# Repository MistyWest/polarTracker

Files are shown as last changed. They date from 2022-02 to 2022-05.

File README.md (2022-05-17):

# WWF ARGOS Tracker

This is the open-source repo for Polar Bear Tracker designed by MistyWest and IDEO for the World Wildlife Fund and US Fish & Wildlife Services. 
For more information see the [blog post](https://www.mistywest.com/posts/project/wwf-polar-bear-tracker/) from MistyWest on the project.

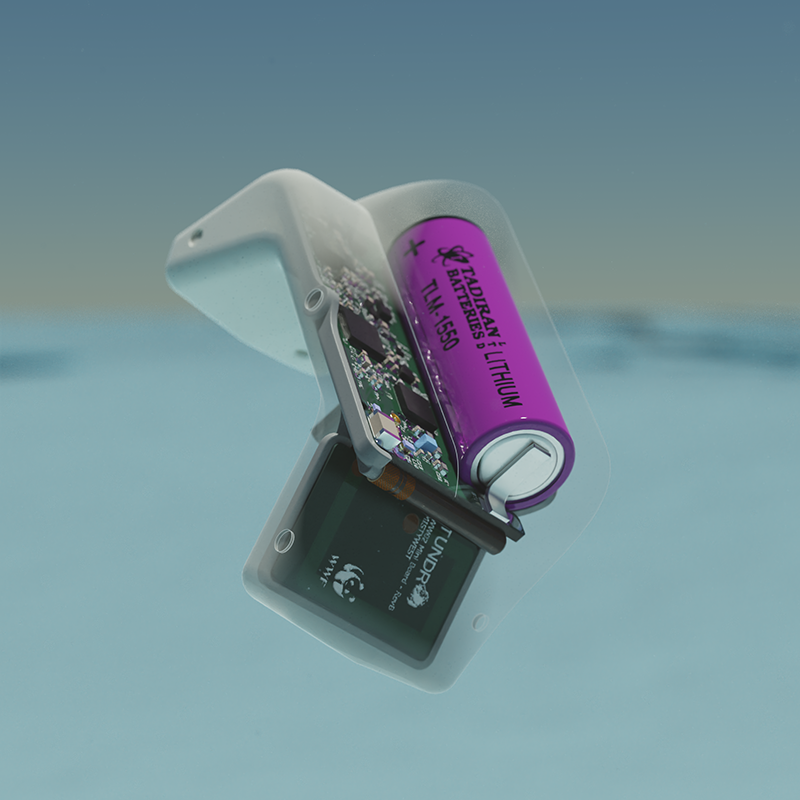
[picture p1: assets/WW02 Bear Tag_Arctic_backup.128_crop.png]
Polar tracker

FWS |  MW | WWF
:-------------------------:|:-------------------------:|:-------------------------:
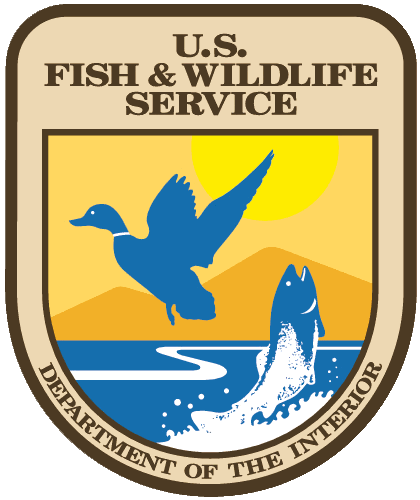
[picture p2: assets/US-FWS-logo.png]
FWS
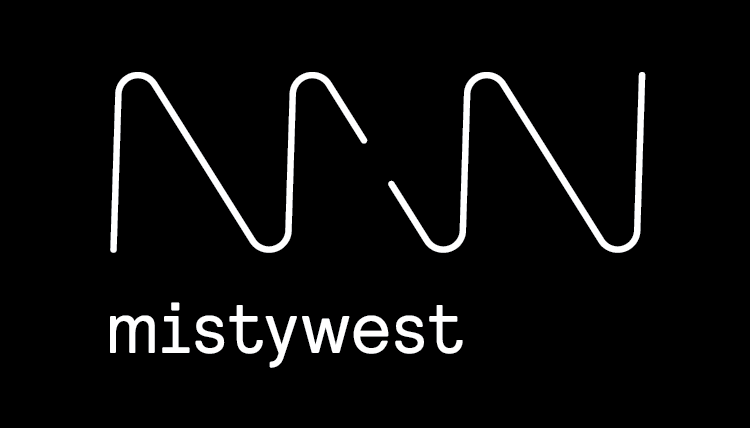
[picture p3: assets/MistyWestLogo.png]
MistyWest
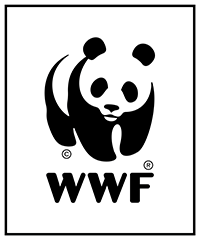
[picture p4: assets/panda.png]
WWF
  |   | 

# Usage Guide

## Quick Start
### EE
- [Design Files](Electrical/Design%20Files)
- [PCB Output Files](Electrical/PCB%20Output%20Files)
### ME
- [Mold Files](Mechanical/Mold%20v3)
### FW
- [Bootloader](Firmware/wwf_bootloader)
- [Firmware](Firmware/ww02Firmware)
    > 1. Initially the board need to be flash using a J-link \
      2.  Any addtionally changes can be be done with the NRF Connect app
      >

## main.c

This is the starting/jump off point for the code. All major threads are started/initialized here.  
You can control the sequence of thread start-up or enable/disable threads via 
```
project_settings.h
```

## Logging/CLI
These are actually two different components.  
CLI is a command line interface which allows for manual
control.  This can be used for debugging and/or user interface.  You can send Text to the terminal
through API called seen in:
```
mw_cli_thread.h
```

Logging is primary for debugging code during development. A wrapper is created around the Nordic SDK
Logging module.  it must be enabled in the SDK config file, where you can also specify either a UART 
or RTT (J-Link) physical interface. This should be a different interface than CLI
```
sdk_config.h

#define NRF_LOG_ENABLED 1

#define NRF_LOG_BACKEND_UART_ENABLED (0:1)

#define NRF_LOG_BACKEND_RTT_ENABLED (0:1)
```

## ADC
The ADC thread uses the Nordic SAADC peripheral driver and is provided as an example of ADC usage.
SAADC must be enabled in the SDK Config file
```
sdk_config.h

#define NRFX_SAADC_ENABLED 1
```

## Current Status:
- Device only works when compiled under DEBUG mode in the Makefile.  Core issue is related to the interface between the nRF52 and ARTIC chip.

## Documentation

Doxygen is used to build the source code documentation. Go to the [downloads page](http://www.doxygen.nl/download.html), scroll down to **Sources and Binaries** and select the latest archive for Linux, Windows, or Mac.

Or if on Linux, just do:

```
sudo apt install doxygen
```

To build the documentation:

```
cd _docs/
doxygen
```

Then use your browser to open `_docs/html/index.html`.

## Contributors
MistyWest
- Kevin Lockwood
- Daniel Law
- Fred Huang
- Victor Hu
- John Turner
- Sean Edmond
- Justin Lam
- Nathan Van Rumpt
- Ryan Wilson
- Michelle St. Martin
- Elisabeth Kruger
- Kayvon Shakeri
- Peter Bronk
- Remy Pieron
- Phil Tsao

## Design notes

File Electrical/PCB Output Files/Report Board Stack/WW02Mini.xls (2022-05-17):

Board Stack Report
Stack Up |  |  | Layer Stack
Layer | Board Layer Stack | Flex | Name | Material | Thickness | Constant
1 |  |  | Top Paste
2 |  |  | Top Overlay
3 |  |  | Top Solder | Solder Resist | 0.60mil | 3.5
4 |  |  | Top Layer | Copper | 1.40mil
5 |  |  | Dielectric 1 | FR-4 | 10.00mil | 4.2
6 |  |  | Signal Layer 1 | Copper | 0.70mil
7 |  |  | Dielectric 3 | PP-006 | 3.30mil | 4.1
8 |  |  | Dielectric 6 | Core-009 | 10.00mil | 4.5
9 |  |  | Dielectric 7 | PP-006 | 2.90mil | 4.1
10 |  |  | Signal Layer 2 | Copper | 0.70mil
11 |  |  | Dielectric 4 |  | 2.00mil | 4.2
12 |  |  | Signal Layer 3 | Copper | 0.70mil
13 |  |  | Dielectric 9 | PP-006 | 3.40mil | 4.1
14 |  |  | Dielectric 8 | Core-009 | 10.00mil | 4.5
15 |  |  | Dielectric 5 | PP-006 | 3.30mil | 4.1
16 |  |  | Signal Layer 4 | Copper | 0.70mil
17 |  |  | Dielectric 2 |  | 10.00mil | 4.2
18 |  |  | Bottom Layer | Copper | 1.40mil
19 |  |  | Bottom Solder | Solder Resist | 0.60mil | 3.5
20 |  |  | Bottom Overlay
21 |  |  | Bottom Paste
 | Height : 61.70mil | Height : 29.70mil

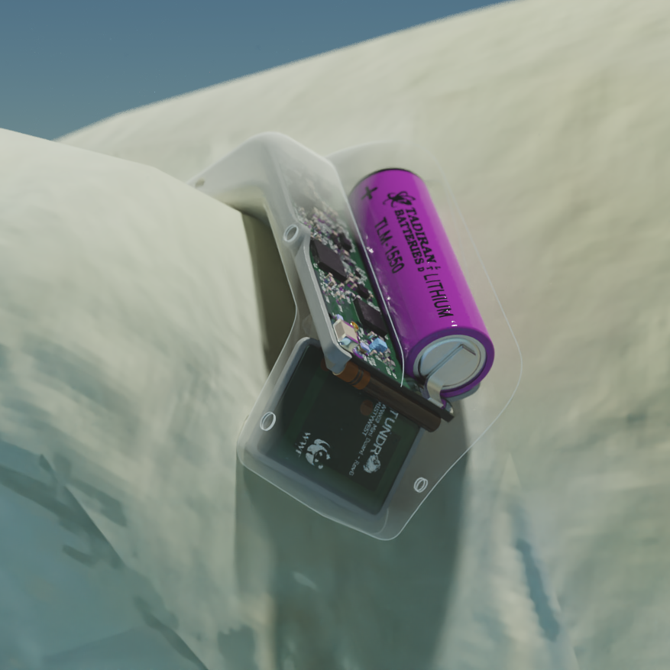
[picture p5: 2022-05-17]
Mechanical/Photos/WW02_Render01.png

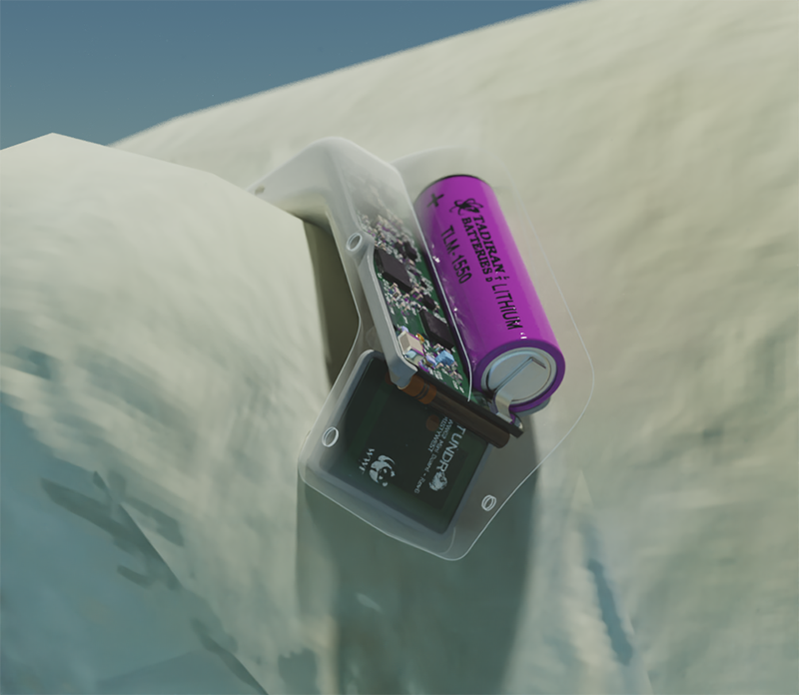
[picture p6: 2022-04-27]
Mechanical/Photos/WW02 Bear Tag_Arctic_backup3.126.png

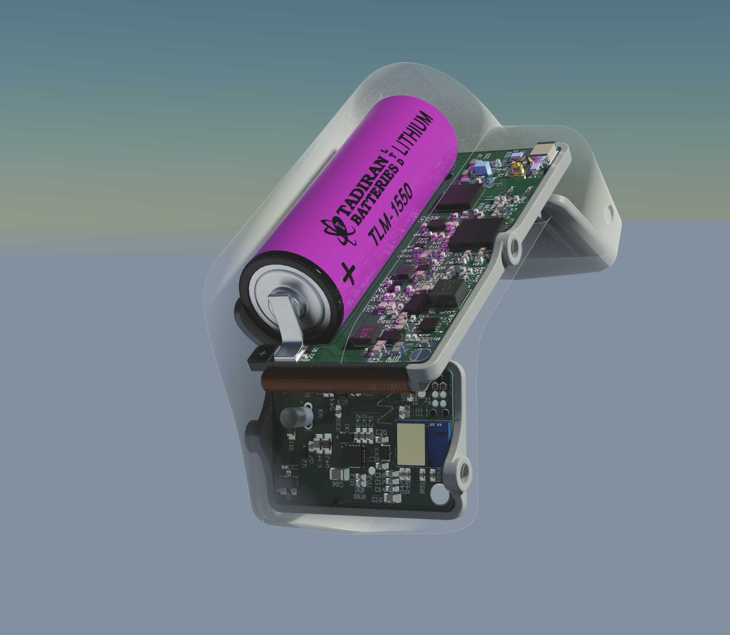
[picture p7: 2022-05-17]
Mechanical/Photos/WW02 Bear Tag_Arctic_backup.135.png

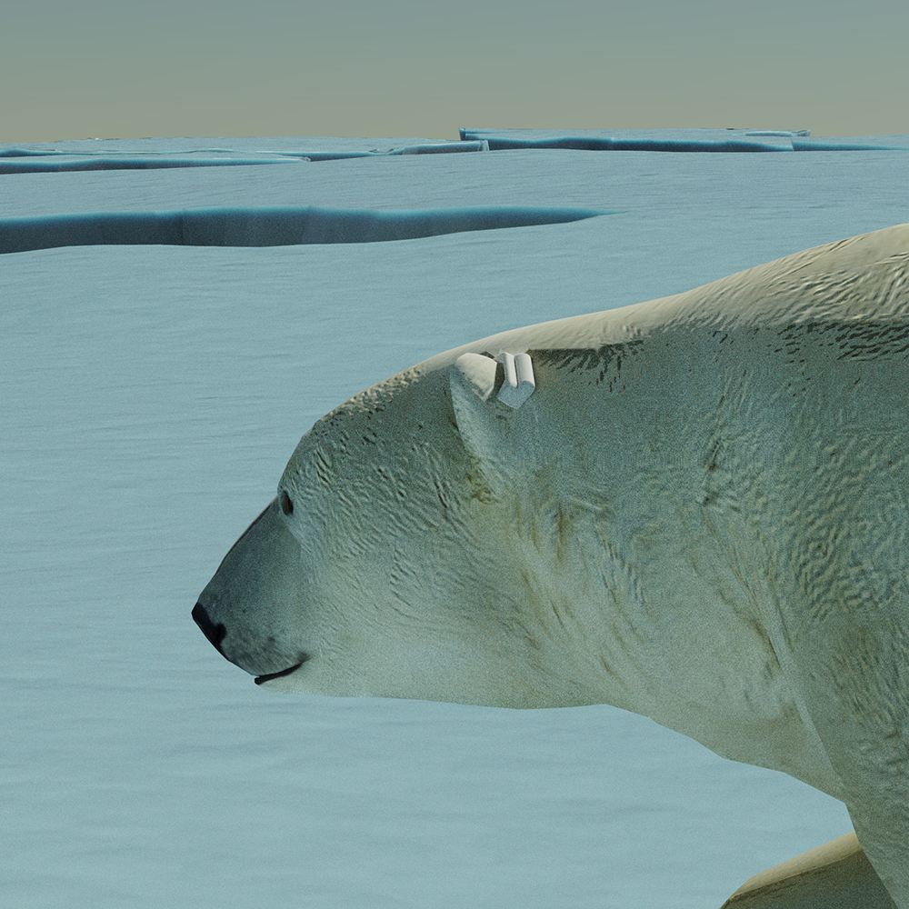
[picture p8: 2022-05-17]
Mechanical/Photos/WW02_Render02.png

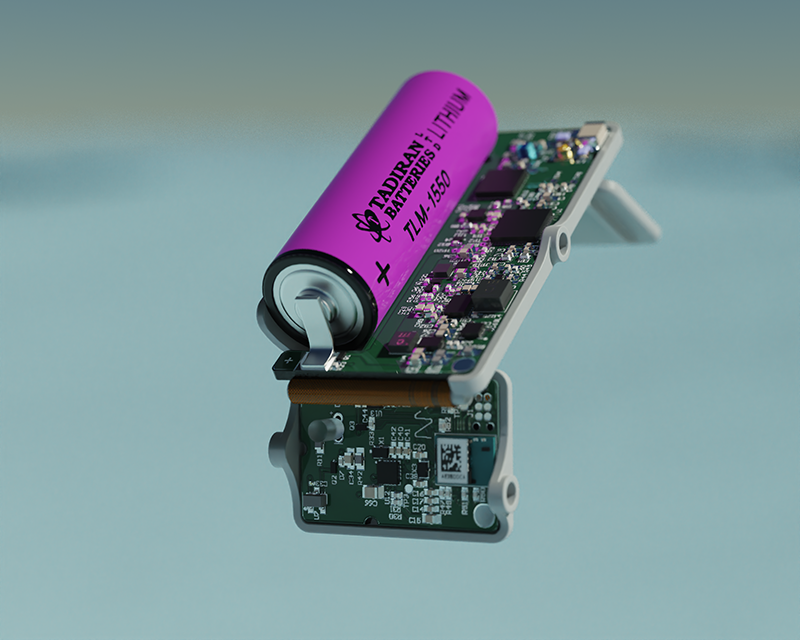
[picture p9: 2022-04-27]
Mechanical/Photos/WW02 Bear Tag_Arctic_backup.137.png

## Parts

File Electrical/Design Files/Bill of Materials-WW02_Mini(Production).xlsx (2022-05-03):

Designator | Quantity | Comment | Description | Manufacturer | Manufacturer Part Number
BT1 | 1 | TLP-96311/A/ST |  | Tadiran | TLP-96311/A/ST
C1 | 1 | 22µF | CAP CER 22UF 6.3V X5R 0603 ±10% | Samsung Electro-Mechanics America, Inc. | CL10A226KQ8NRNE
C2, C14, C18, C40, C43, C46, C47 | 7 | 1µF | CAP CER 1UF 6.3V X7R 0402 ±10% | Samsung Electro-Mechanics America, Inc. | CL05B105KQ5NQNC
C3, C4, C6, C8, C10, C12, C15, C16, C19, C28, C41, C44, C61 | 13 | 100nF | CAP CER 0.1UF 10V X7R 0402 ±5% | Samsung Electro-Mechanics America, Inc. | CL05B104JP5NNNC
C5, C7, C9, C11, C13, C62 | 6 | 22pF | CAP CER 22PF 50V C0G/NP0 0402 ±5% | Samsung Electro-Mechanics America, Inc. | CL05C220JB5NNNC
C17, C25, C26, C27, C30, C31, C32 | 7 | 22µF 6.3V X5R | CAP CER 22UF 6.3V X5R 0603 ±10% | Samsung Electro-Mechanics America, Inc. | CL10A226KQ8NRNE
C20, C38 | 2 | 20pF | CAP CER 20PF 50V C0G/NP0 0402 ±5% | Samsung Electro-Mechanics America, Inc. | CL05C200JB5NNNC
C21 | 1 | 1.8pF | CAP CER 1.8PF 50V C0G/NP0 0402 ±0.25pF | Samsung Electro-Mechanics America, Inc. | CL05C1R8CB5NNNC
C22, C23, C35, C60 | 4 | 10pF | CAP CER 10PF 50V C0G/NP0 0402 ±0.25pF, CAP CER 10PF 50V C0G/NP0 0402 ±0.5pF | Samsung Electro-Mechanics America, Inc. | CL05C100CB5NNNC, CL05C100DB5NNNC
C24, C29, C34 | 3 | 2.2uF | CAP CER 2.2uF 6.3V X7R 0603 ±10% | Samsung Electro-Mechanics America, Inc. | CL10B225KQ8NNNC
C33 | 1 | 15nF | CAP CER 15nF 6.3V X5R 0201 ±10% | Samsung Electro-Mechanics America, Inc. | CL03A153KQ3NNNC
C36, C37 | 2 | 10µF 6.3V X5R | CAP CER 10UF 6.3V X5R 0603 ±10% | Samsung Electro-Mechanics America, Inc. | CL10A106KQ8NNNC
C39, C49 | 2 | 100pF | CAP CER 100PF 50V C0G/NP0 0402 ±5% AEC-Q200 | Samsung Electro-Mechanics America, Inc. | CL05C101JB51PNC
C42, C90 | 2 | 47pF | CAP CER 47PF 50V C0G/NP0 0402 ±5%, CAP CER 47PF 50V C0G/NP0 0402 ±5% AEC-Q200 | Samsung Electro-Mechanics America, Inc. | CL05C470JB5NNNC, CL05C470JB51PNC
C45, C48 | 2 | 220nF | CAP CER 0.22UF 10V X7R 0402 ±10% | Samsung Electro-Mechanics America, Inc. | CL05B224KP5NNNC
C50 | 1 | 5.5-30pF 125V Trimmer | CAP TRIMMER 5.5-30PF 125V SMD | Knowles Voltronics | JR300
C51 | 1 | 33pF | CAP CER 33PF 50V C0G/NP0 0402 ±5% | Samsung Electro-Mechanics America, Inc. | CL05C330JB5NNNC
C63, C64, C89 | 3 | 10nF | CAP CER 10000PF 10V X7R 0402 ±10% | Samsung Electro-Mechanics America, Inc. | CL05B103KP5NNNC
C65 | 1 | 1.0uF | CAP CER 1.0uF 6.3V X7R 0603 ±10% | Samsung Electro-Mechanics America, Inc. | CL10B105KQ8NNN
C66 | 1 | 47µF | CAP CER 47UF 6.3V X5R 0805 ±20% | Samsung Electro-Mechanics America, Inc. | CL21A476MQCLRNC
C67, C68 | 2 | 470nF | CAP CER 470nF 6.3V X5R 0201 ±10% | Samsung Electro-Mechanics America, Inc. | CL03A474KQ3NNNC
C91 | 1 | 680pF | CAP CER 680PF 50V C0G/NP0 0402 ±5% | Samsung Electro-Mechanics America, Inc. | CL05C681JB5NNNC
C92 | 1 | 6.8pF | CAP CER 6.8PF 50V C0G/NP0 0402 ±0.25pF | Samsung Electro-Mechanics America, Inc. | CL05C6R8CB5NNNC
D5 | 1 | WP710A10LSECK/J3 | Red 625nm LED Indication - Discrete 1.8V Radial | Kingbright | WP710A10LSECK/J3
D7 | 1 | CDBQR0130L | Diode Schottky 30V 100mA Surface Mount 0402/SOD-923F | Comchip Technology | CDBQR0130L
FB1, FB2, FB4, FB7, FB8, FB9, FB10 | 7 | BLM15AG221SN1D | Chip Ferrite Bead for General Use, 220 Ohm, 450 mA, -55 to 125 degC, 1 x 0.5 x 0.55 mm SMD, Tape and Reel | Murata | BLM15AG221SN1D
J2, J3 | 2 | CONNECTOR COAX-M 2GND | CONN RECPT ULTRA-MINI COAX SMD | HIROSE | U.FL-R-SMT(10)
L3 | 1 | 2.2uH 1.4A | XFL3012-222ME_ | CoilCraft | XFL3012-222ME_
L4 | 1 | 2.2u | XAL4020-222ME | CoilCraft | XAL4020-222ME
L5 | 1 | 2.2uH | XPL2010-222ML | CoilCraft | XPL2010-222ML
L8 | 1 | 15nH | FIXED IND 15NH 1.5A 120 MOHM | MuRata | LQW2BAN15NG00L
L9 | 1 | 6.8nH | 0603HP-6N8X_E_ | Coilcraft | 0603HP-6N8X_E_
Q1, Q3, Q4, Q5 | 4 | CSD23285F5T | P-Channel 12V 5.4A (Ta) 500mW (Ta) Surface Mount 3-PICOSTAR | Texas Instruments | CSD23285F5T
Q2, Q6 | 2 | CSD17585F5T | N-Channel 30V 5.9A (Ta) 500mW (Ta) Surface Mount 3-PICOSTAR | Texas Instruments | CSD17585F5T
R1, R8, R47, R48, R49, R50, R51, R52, R53 | 9 | 0 | RES SMD 0.0OHM JUMPER 1/16W 0402 | Yageo | RC0402JR-070RL
R2, R3 | 2 | 100k | RES SMD 100K OHM 1% 1/10W 0402 | Panasonic Electronic Components | ERJ-2RKF1003X
R5 | 1 | 5.6 | RES SMD 5.6 OHM 1% 1/4W 0603 | Panasonic | ERJ-3BQF5R6V
R6, R7 | 2 | 910 | PANASONIC ERJPA3F9100V RESISTOR, ERJP, 910 OHM, 0603, 0.25W, 1% | Panasonic | ERJ-PA3F9100V
R9 | 1 | 33k | RES SMD 33K OHM 1% 1/10W 0402 | Panasonic Electronic Components | ERJ-2RKF3302X
R11 | 1 | 750R | 750R 0.1W ±5% | Yageo | RC0603JR-07750RL
R15, R20 | 2 | 1M | RES SMD 1M OHM 1% 1/16W 0402 | Yageo | RC0402FR-071ML
R16 | 1 | 402k | RES SMD 402K OHM 1% 1/10W 0402 | Panasonic Electronic Components | ERJ-2RKF4023X
R17, R18 | 2 | 0R | 0R 0.1W | Yageo | RC0603JR-070RL
R19 | 1 | ERT-J0ER104HM | NTC Thermistor 100k 0402 (1005 Metric) | Panasonic Electronic Components | ERT-J0ER104HM
R21, R23, R32, R33, R56 | 5 | 3.6M | RES SMD 3.6M OHM 1% 1/16W 0402 | Yageo | RC0402FR-073M6L
R22 | 1 | 1.74M | RES SMD 1.74M OHM 1% 1/16W 0402 | Yageo | RC0402FR-071M74L
R24 | 1 | 1.3M | RES SMD 1.3M OHM 1% 1/16W 0402 | Yageo | RC0402FR-071M3L
R25 | 1 | 32.4k | RES SMD 32.4K OHM 1% 1/10W 0402 | Panasonic Electronic Components | ERJ-2RKF3242X
R26 | 1 | 20k | RES SMD 20K OHM 1% 1/10W 0402 | Panasonic Electronic Components | ERJ-2RKF2002X
R30, R31, R36, R37 | 4 | 4.7k | RES SMD 4.7K OHM 1% 1/10W 0402 | Panasonic Electronic Components | ERJ-2RKF4701X
R42, R59, R60 | 3 | 4.7M | RES SMD 4.7M ±1% 0.1W, 1/10W 0603 | Yageo | RC0603FR-074M7L
R43, R44, R45 | 3 | 3.3M | RES SMD 3.3M OHM 1% 1/16W 0402 | Yageo | RC0402FR-073M3L
R46 | 1 | 5.1M | RES SMD 5.1M OHM 1% 1/16W 0402 | Yageo | RC0402FR-075M1L
R54, R58 | 2 | 1M | RES SMD 1M OHM 1% 1/10W 0402 | Panasonic Electronic Components | ERJ-2RKF1004X
R66 | 1 | 27.4k | RES SMD 27.4KOHM 0.1% 1/16W 0402 ±10ppm/°C | TE Connectivity Passive Product | RN73C1E27K4BTD
U1 | 1 | ARTIC | Ansem ARTIC | Ansem | ARTIC
U2 | 1 | BMD-350-A-R | MOD BLE 4.2 NORDIC NRF52832 SOC | Rigado, Inc. | BMD-350-A-R
U3 | 1 | RFFM6404 | Transmit/Receive Module, 2.5V to 4.5V, ISM Band, 27.5dBm, 430MHz to 450MHz | Qorvo | RFFM6404TR13
U4 | 1 | LTC3539EDCB#TRPBF | 2 A, 1 MHz / 2 MHz Synchronous Step-Up DC/DC Converter, 8-pin SON (DCB-8), -40 to 85 degC, Pb-Free, Tape and Reel | Linear Technology | LTC3539EDCB#TRPBF
U5 | 1 | LTC3533EDE#TRPBF | 2 A Wide Input Voltage Synchronous Buck-Boost DC/DC Converter, 14-pin SON (DE-14), -40 to 85 degC, Pb-Free, Tape and Reel | Linear Technology | LTC3533EDE#TRPBF
U6 | 1 | TLV3691IDPFR | Comparator General Purpose Push-Pull 6-X2SON (1x1) | Texas Instruments | TLV3691IDPFR
U7 | 1 | AH182-WG-7 | Low Power Hall Effect Switch, 2.5 to 5.5 V, -40 to 85 degC, 3-Pin SC59, RoHS, Tape and Reel | Diodes Incorporated | AH182-WG-7
U8 | 1 | ADP5301ACBZ-1-R7CT-ND | Buck Switching Regulator IC Positive Programmable 0.8V 1 Output 50mA, 500mA 9-WFBGA, WLCSP | ADP5301ACBZ-1-R7 | ADP5301ACBZ-1-R7
U11 | 1 | LPS33HWTR | Pressure Sensor 3.77 PSI ~ 18.27 PSI (26 kPa ~ 126 kPa) Absolute 24 b LGA | STMicroelectronics | LPS33HWTR
U12 | 1 | AM0805AQ | Real Time Clock (RTC) IC 16-VFQFN Exposed Pad | Ambiq Micro, Inc. | AM0805AQ
U13 | 1 | ISM303DACTR | Accelerometer and Magnetometer Sensor I²C, SPI Output | STMicroelectronics | ISM303DACTR
U15 | 1 | LP5900SD-2.7/NOPB | Ultra Low Noise, 150mA Linear Regulator for RF/Analog Circuits Requires No Bypass Capacitor, 6-pin LLP, Pb-Free | Texas Instruments | LP5900SD-2.7/NOPB
X1 | 1 | ABS06-32.768KHZ-1-T | 32.768kHz ±10ppm Crystal 12.5pF 90 kOhms 2-SMD, No Lead | Abracon LLC | ABS06-32.768KHZ-1-T
X2 | 1 | KT2520K26000AAW18TAS | 26MHz TCXO Clipped Sine Wave Oscillator 1.8V 6-SMD, No Lead | Kyocera International Inc. Electronic Components | KT2520K26000AAW18TAS
X3 | 1 | ECS-.327-12.5-12R-C-TR | 32.768kHz ±10ppm Crystal 12.5pF 70 kOhms 2-SMD, No Lead | ECS Inc. | ECS-.327-12.5-12R-C-TR

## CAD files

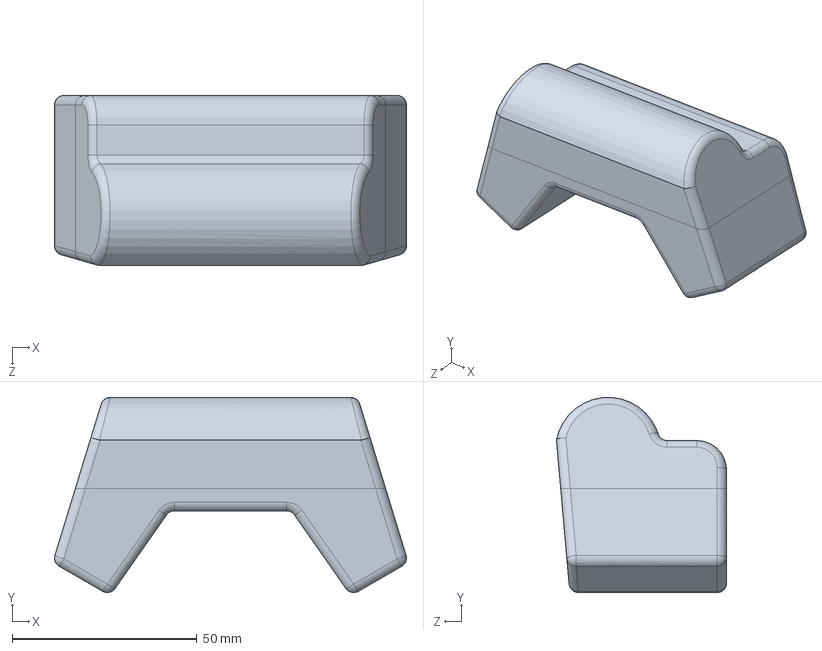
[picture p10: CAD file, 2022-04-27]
Mechanical/3D Printed Mold v3/FULL_3D_printed_enclosure.SLDPRT
95.2 x 52.8 x 46.0 mm

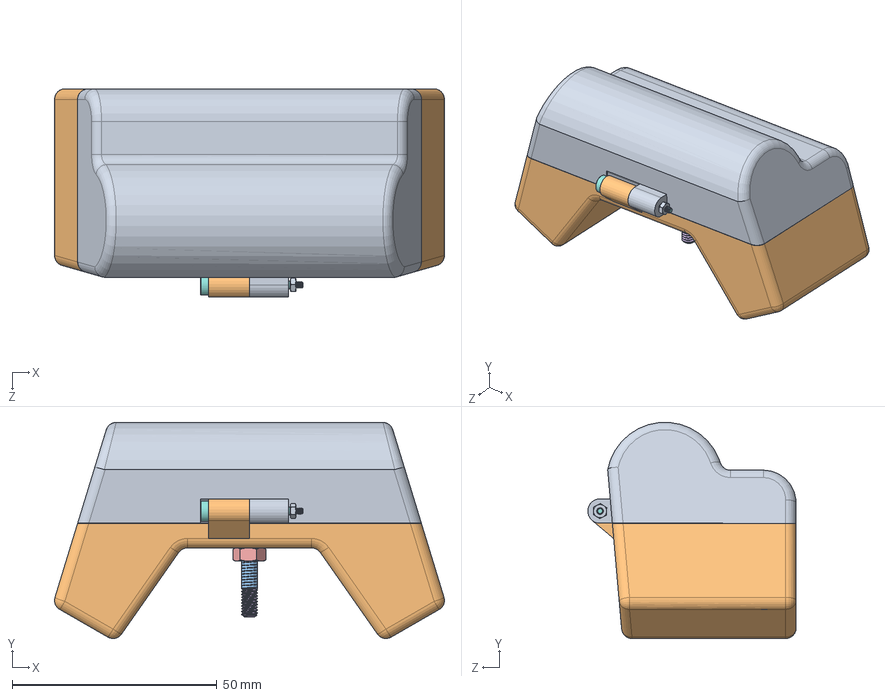
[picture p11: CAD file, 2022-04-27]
Mechanical/3D Printed Mold v3/ASSEM_3D_printed_enclosure.SLDASM
95.2 x 52.8 x 50.8 mm
(B)ear Tag_7_30_2020
ww02_Board_Render
90592A090_Steel Hex Nut
90358A009_Ultra-Low-Profile Socket Head Screw
BOTTOM_3D_printed_enclosure
TOP_3D_printed_enclosure
small_magnet x 8
92981A950_Alloy Steel Shoulder Screws
90591A109_Zinc-Plated Steel Hex Nut

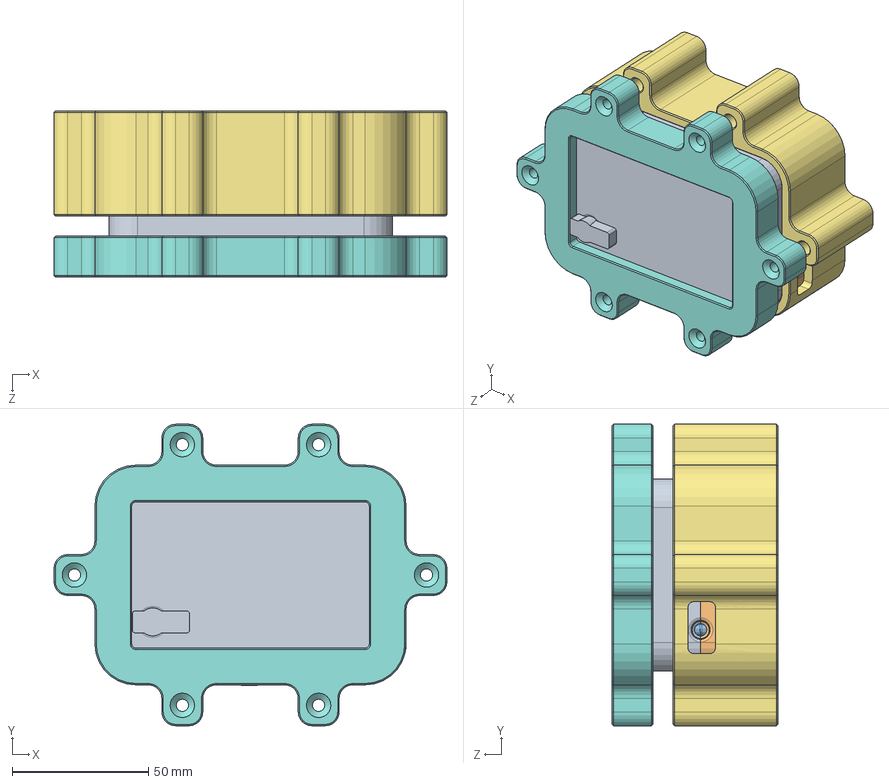
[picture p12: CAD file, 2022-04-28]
Mechanical/Mold v3/ASSEM Potted Case Mold.SLDASM
144.1 x 110.6 x 60.9 mm
Mold v3 Female
(B)ear Tag_7_30_2020
ww02_Board_Render
screw
90592A090_STEEL HEX NUT
Mold v3 Male
Mold Clamp 2
Mold Clamp 1
Plug RevB
wire plug

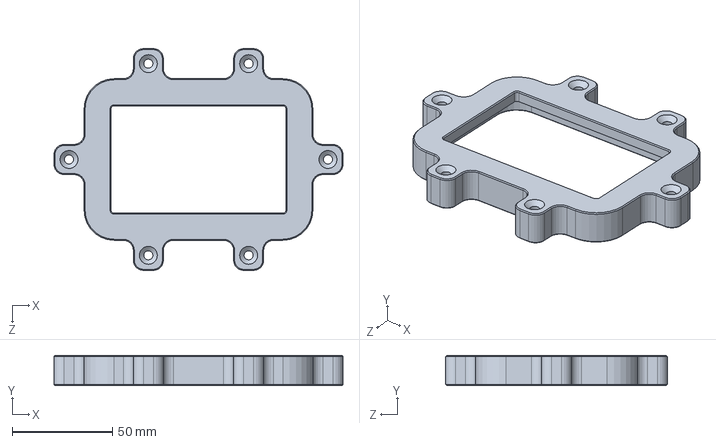
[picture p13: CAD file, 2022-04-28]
Mechanical/Mold v3/Mold Clamp 1.SLDPRT
144.1 x 15.0 x 110.6 mm

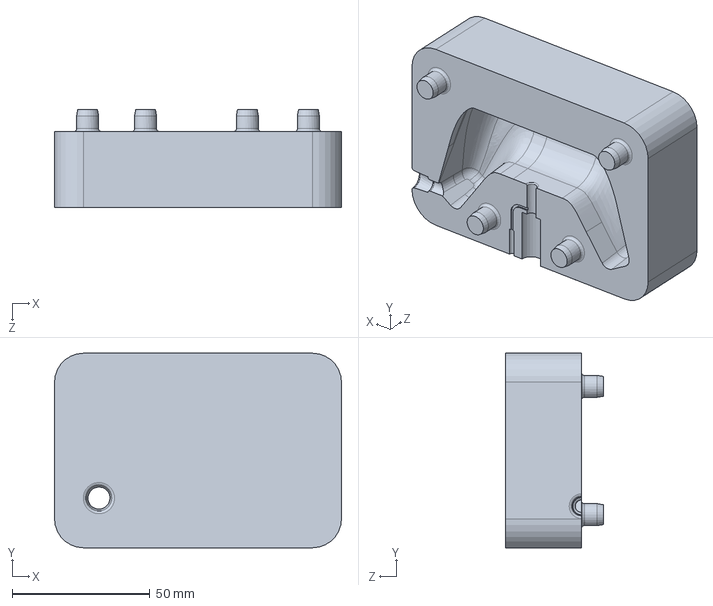
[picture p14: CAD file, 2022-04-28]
Mechanical/Mold v3/Mold v3 Male.SLDPRT
104.0 x 70.5 x 35.6 mm

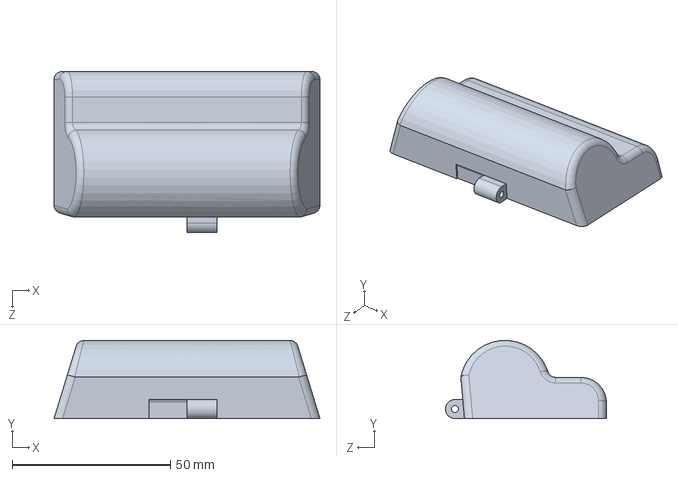
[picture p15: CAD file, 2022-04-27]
Mechanical/3D Printed Mold v3/TOP_3D_printed_enclosure.SLDPRT
83.9 x 24.6 x 50.8 mm

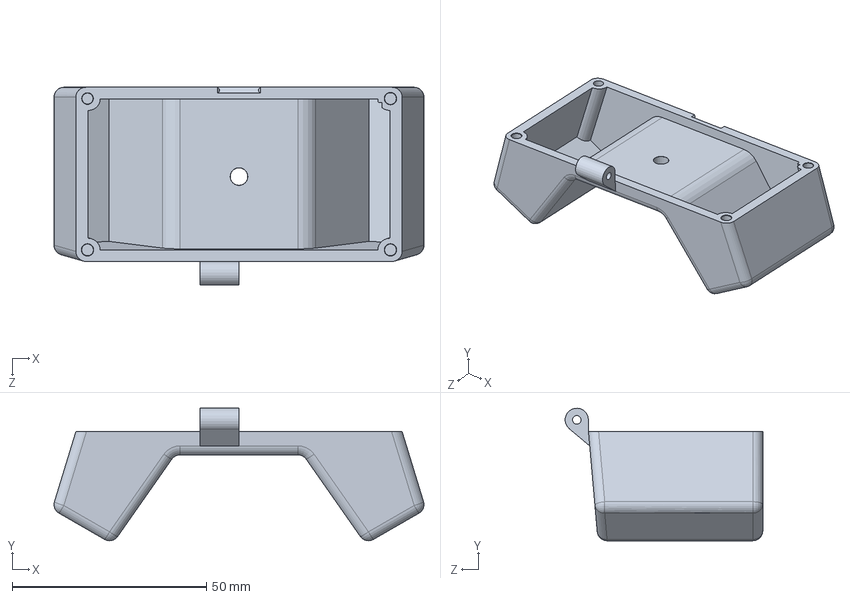
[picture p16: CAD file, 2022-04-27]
Mechanical/3D Printed Mold v3/BOTTOM_3D_printed_enclosure.SLDPRT
95.2 x 34.1 x 50.8 mm

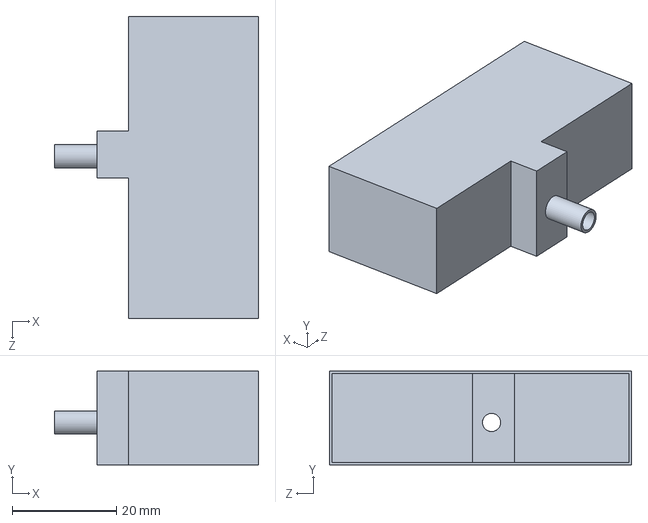
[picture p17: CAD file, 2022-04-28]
Mechanical/Mold v3/urethane reservoir.SLDPRT
39.2 x 18.0 x 58.0 mm

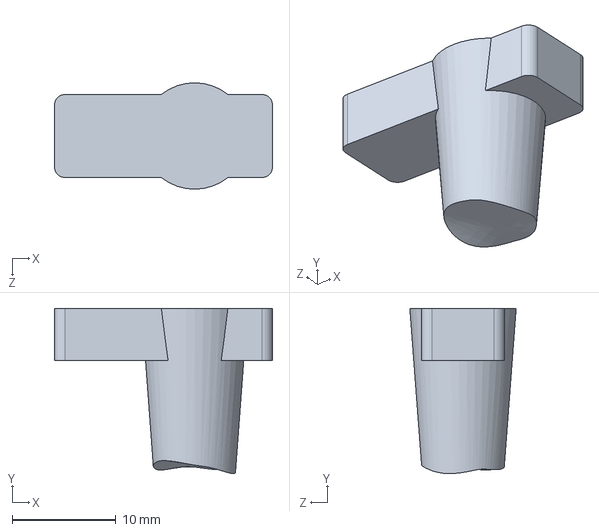
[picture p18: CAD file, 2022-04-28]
Mechanical/Mold v3/Plug RevB.SLDPRT
21.0 x 15.9 x 10.2 mm

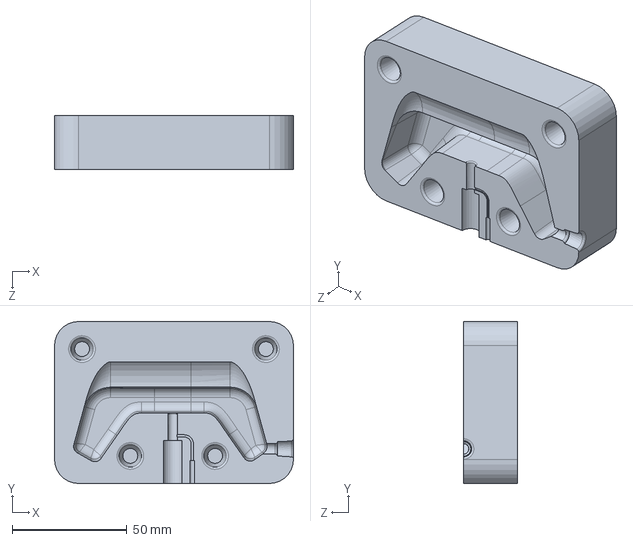
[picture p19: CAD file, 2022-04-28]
Mechanical/Mold v3/Mold v3 Female.sldprt
104.0 x 70.5 x 23.4 mm

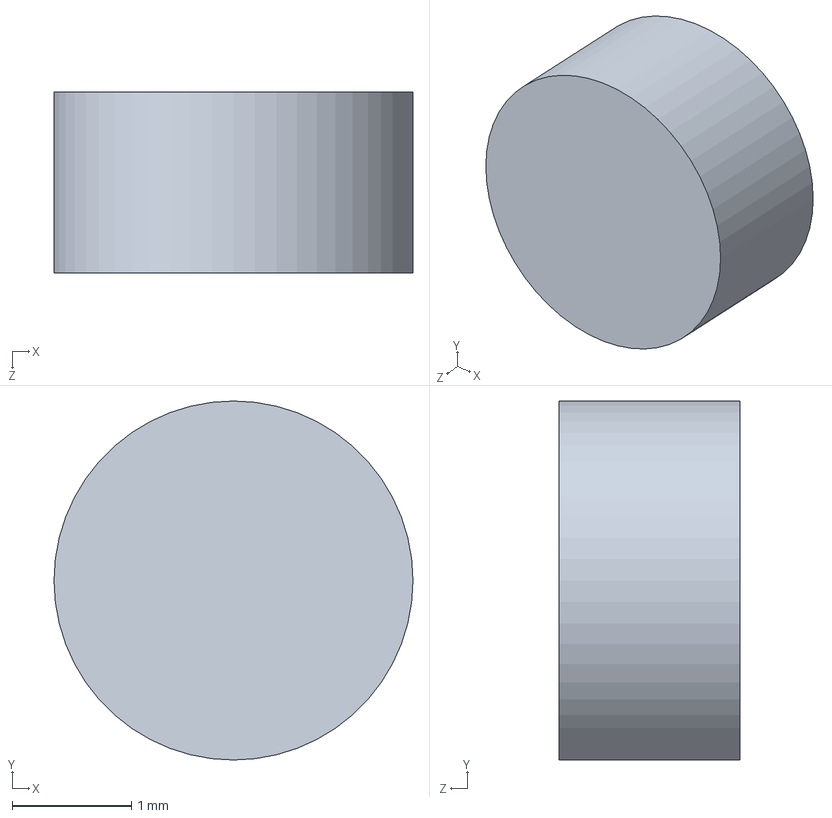
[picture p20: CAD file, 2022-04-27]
Mechanical/3D Printed Mold v3/Hardware/small_magnet.SLDPRT
3.01 x 3.01 x 1.52 mm

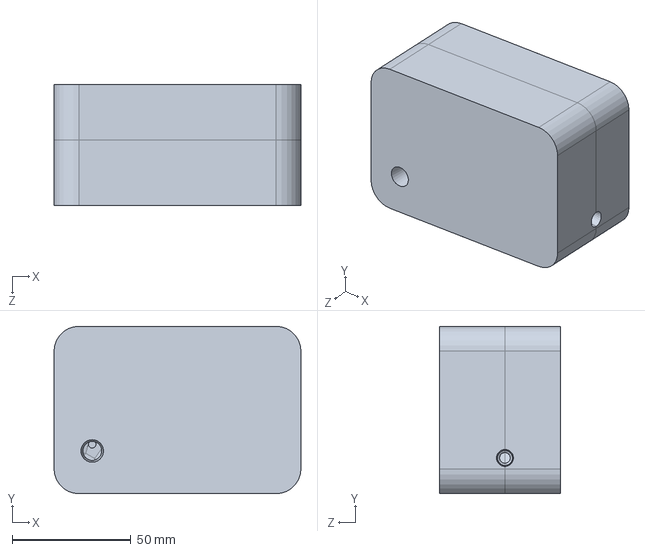
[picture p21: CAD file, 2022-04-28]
Mechanical/Mold v3/Mold v3.sldprt
104.0 x 70.5 x 50.9 mm

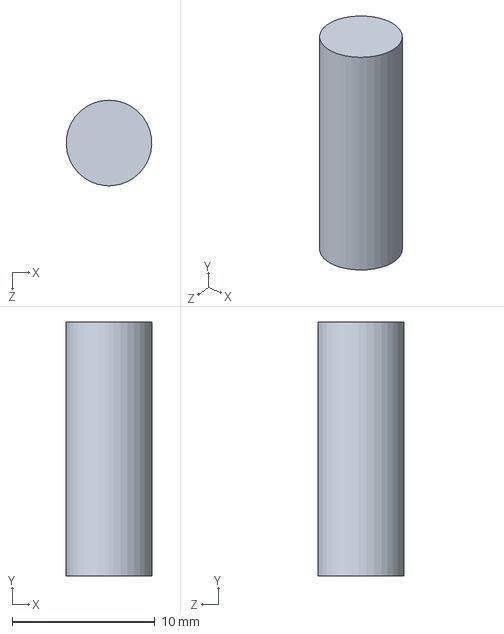
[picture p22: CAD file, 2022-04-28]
Mechanical/Mold v3/wire plug.SLDPRT
5.99 x 17.8 x 6.00 mm

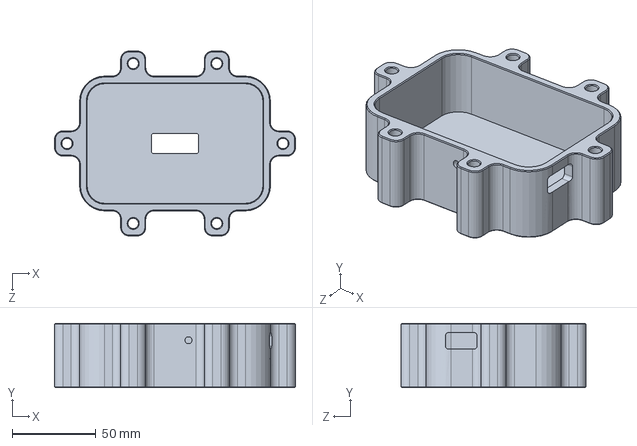
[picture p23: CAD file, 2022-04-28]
Mechanical/Mold v3/Mold Clamp 2.SLDPRT
144.1 x 38.5 x 110.6 mm

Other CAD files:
Mechanical/3D Printed Mold v3/Hardware/90591A109_Zinc-Plated Steel Hex Nut.SLDPRT
Mechanical/Mold v3/Hardware/90592A090_STEEL HEX NUT.SLDPRT
Mechanical/3D Printed Mold v3/Hardware/90358A009_Ultra-Low-Profile Socket Head Screw.SLDPRT
Mechanical/3D Printed Mold v3/Hardware/M4x0.7mmx20mm Ulow_prof.SLDPRT
Mechanical/3D Printed Mold v3/Hardware/90592A090_Steel Hex Nut.SLDPRT
Mechanical/3D Printed Mold v3/Hardware/91829A780_Slotted 18-8 Stainless Steel Precision Shoulder Screw.SLDPRT
Mechanical/3D Printed Mold v3/Hardware/92981A950_Alloy Steel Shoulder Screws.SLDPRT
Mechanical/Mold v3/screw.SLDPRT

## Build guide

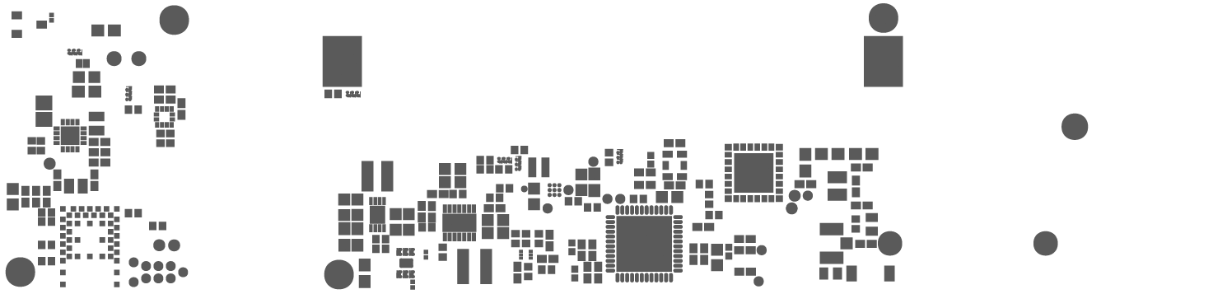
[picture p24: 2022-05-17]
Electrical/PCB Output Files/Gerber/PNG export/Photoshop png export/WW02_0003s_0001_Solder-Pads-copy-3.png

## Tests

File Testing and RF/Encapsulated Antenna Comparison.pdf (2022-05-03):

Valhalla Systems Inc. | April 9, 2021
WWF, Encapsulated Antenna Performance

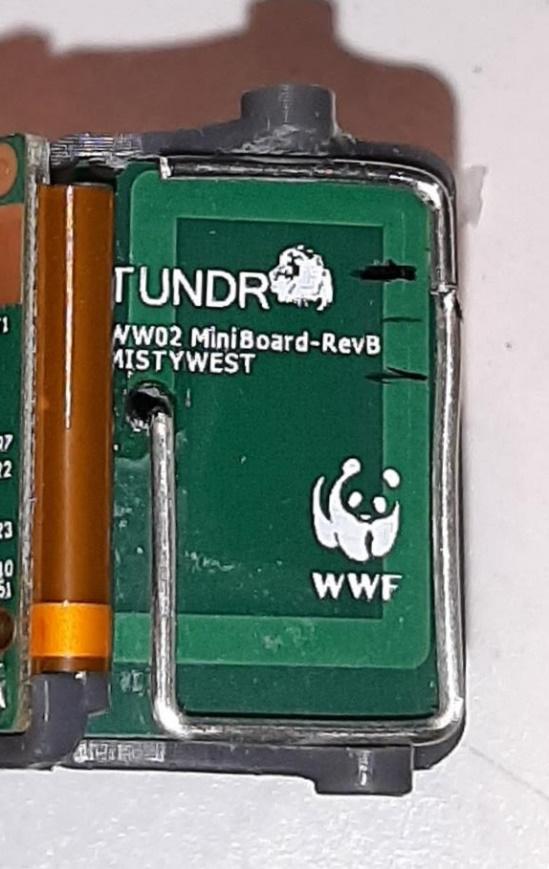
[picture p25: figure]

- Proprietary and Confidential -
Encapsulated Antenna Comparison.docx | ©Valhalla Systems Inc. 2021 | page 1 of 6

The unit encapsulated by Misty West was modifed to extend the length of the resonator into the potting material. A representative sample of the extension is shown below. The resonators on future units should be replaced and trimmed to duplicate the length.

The extension is in the shape of an L, the outside dimensions are 5mm on the short side and 15mm on the long side. This shifts the resonant frequency to ~425 MHz once encapsulated with a tuning range of about 10 MHz. The tuning inductor, L9, is installed as 6.8nH and the fixed series capacitor, C51, is changed to 10pF.

FYI, in air the resonant frequency was measured at 531MHz.

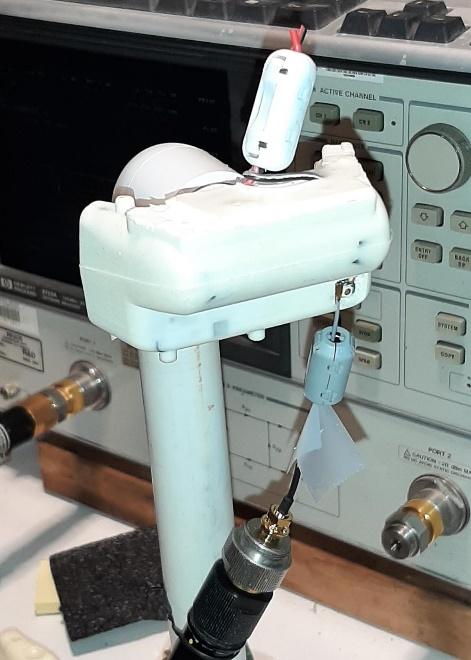
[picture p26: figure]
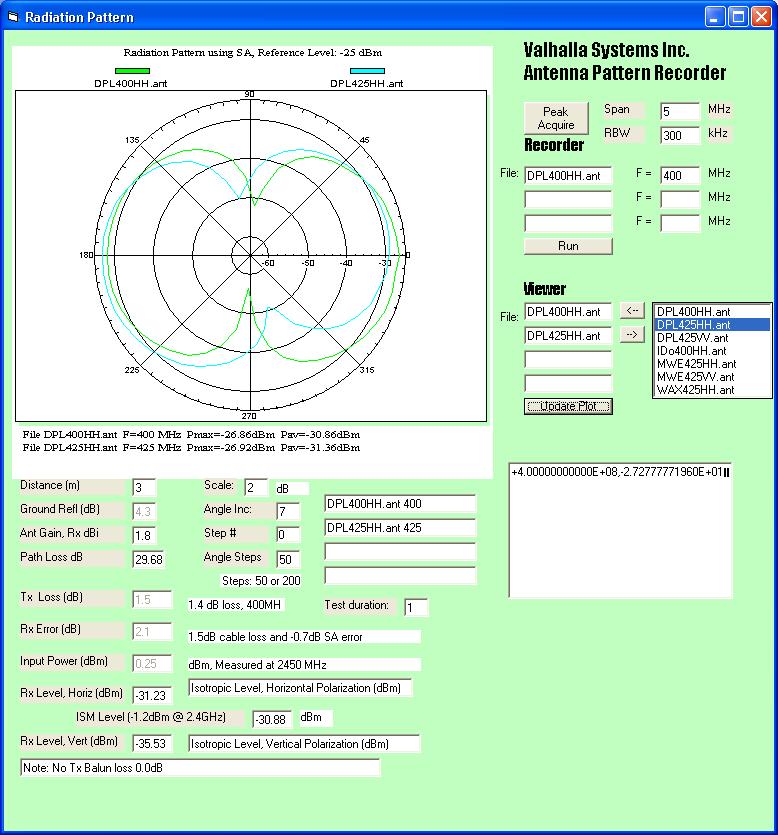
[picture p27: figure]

Encapsulated Antenna Comparison.docx | ©Valhalla Systems Inc. 2021 | page 2 of 6

The radiated performance of the prototype was compared against the original IDEO unit (Jan_20 and tuned to 400 MHz) and the parrafin Wax prototype (Jan_21 and tuned to 425 MHz).

This unit is shown on the PVC test stand.

The same orientation was used for all modules.

This is a plot of the reference dipole antenna measured at 400 and 425 MHz. The received levels are used to estimate gain assuming a dipole of 2dBi.

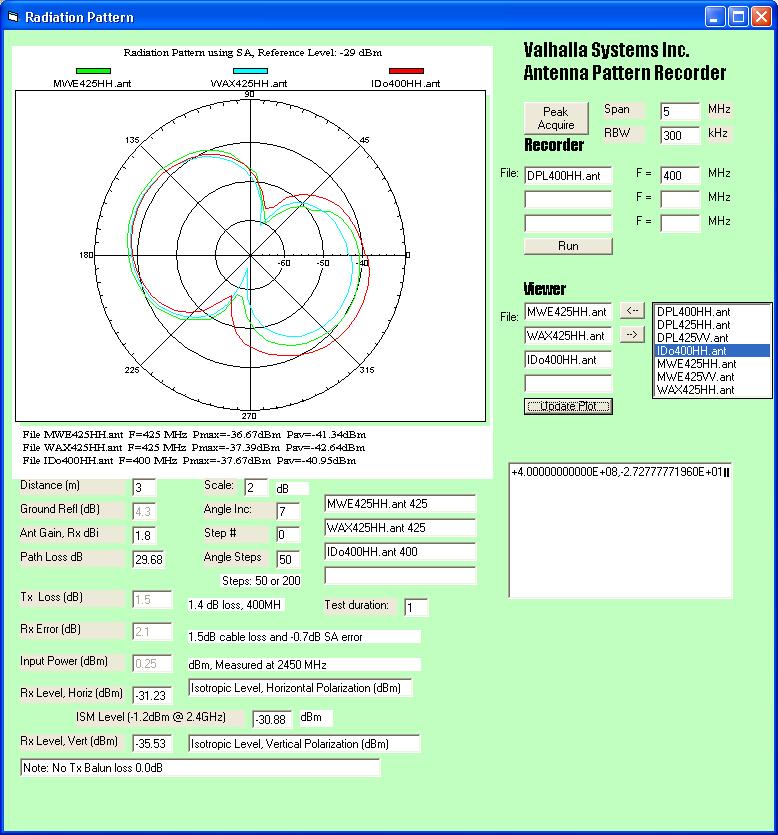
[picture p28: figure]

Encapsulated Antenna Comparison.docx | ©Valhalla Systems Inc. 2021 | page 3 of 6

This is a comparison plot of the three prototypes, IDEO_Jan_20, Wax_Jan_21, and the Misty_West_Apr_21.

Comments:
- All three prototypes show very similar gain characteristics.
- There is some assymetry attributed to difference in construction.
- The peak gain of all three antennas is approximately -8dBi.

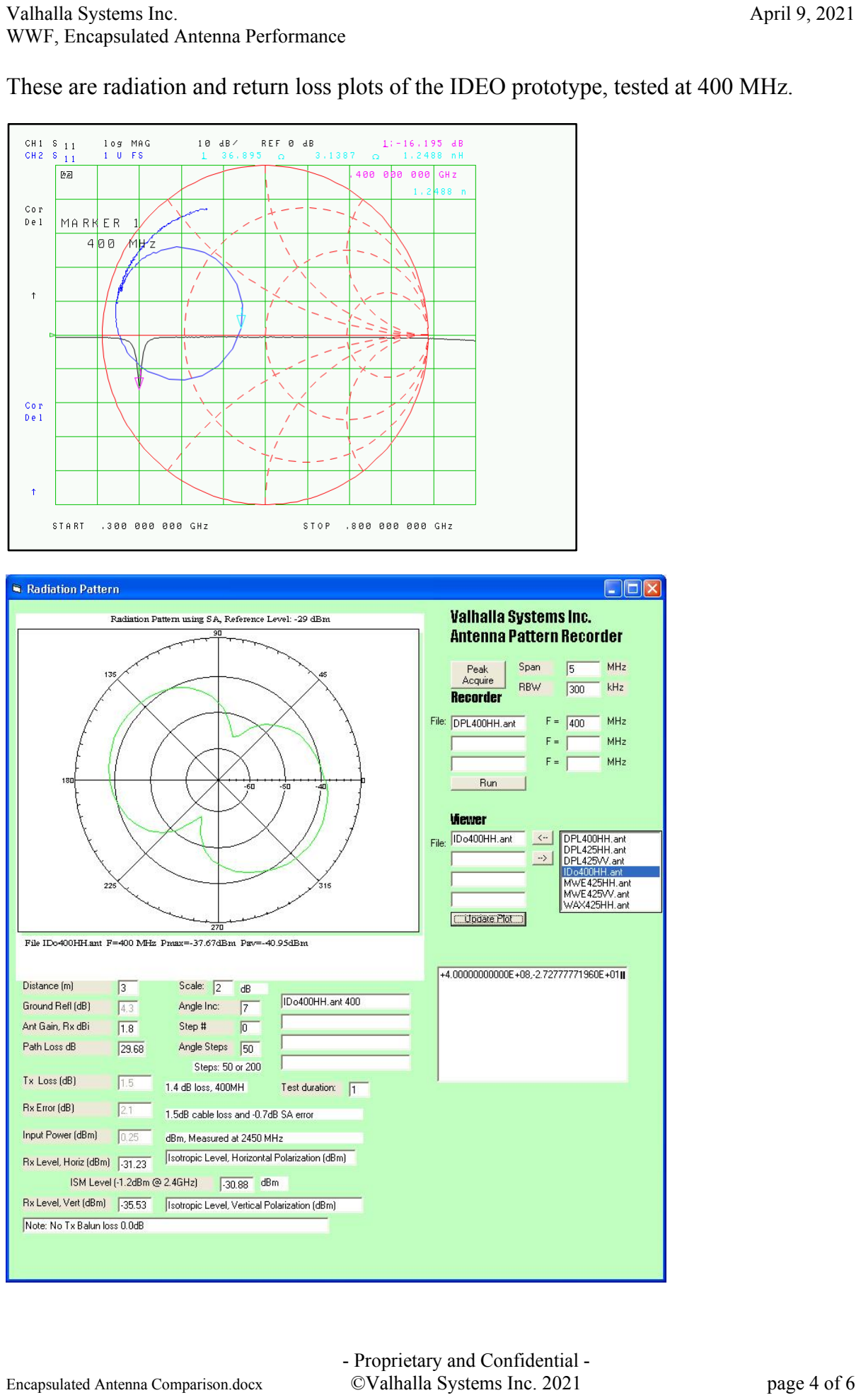
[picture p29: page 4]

Encapsulated Antenna Comparison.docx | ©Valhalla Systems Inc. 2021 | page 4 of 6

These are radiation and return loss plots of the IDEO prototype, tested at 400 MHz.

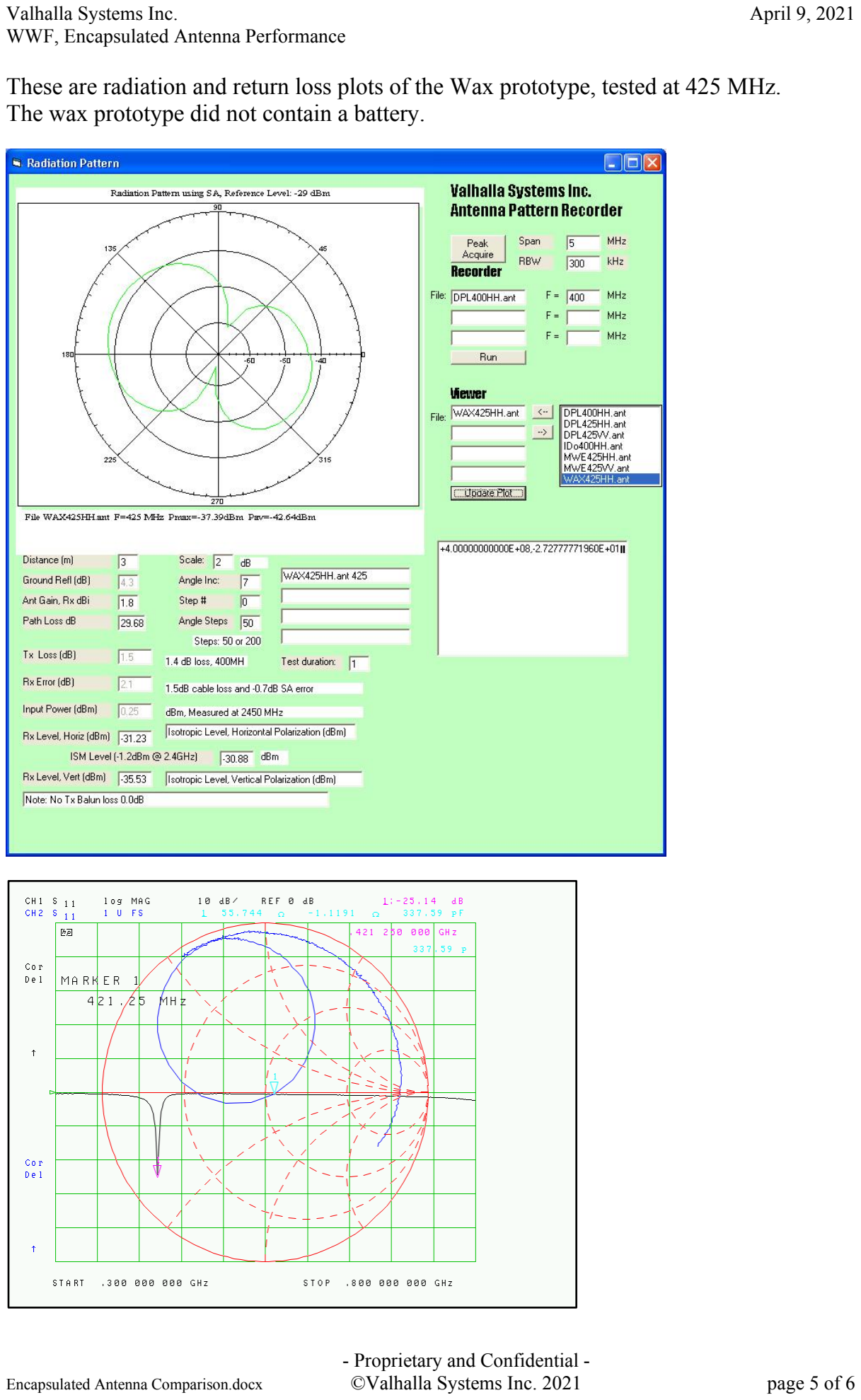
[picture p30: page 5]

Encapsulated Antenna Comparison.docx | ©Valhalla Systems Inc. 2021 | page 5 of 6

These are radiation and return loss plots of the Wax prototype, tested at 425 MHz. The wax prototype did not contain a battery.

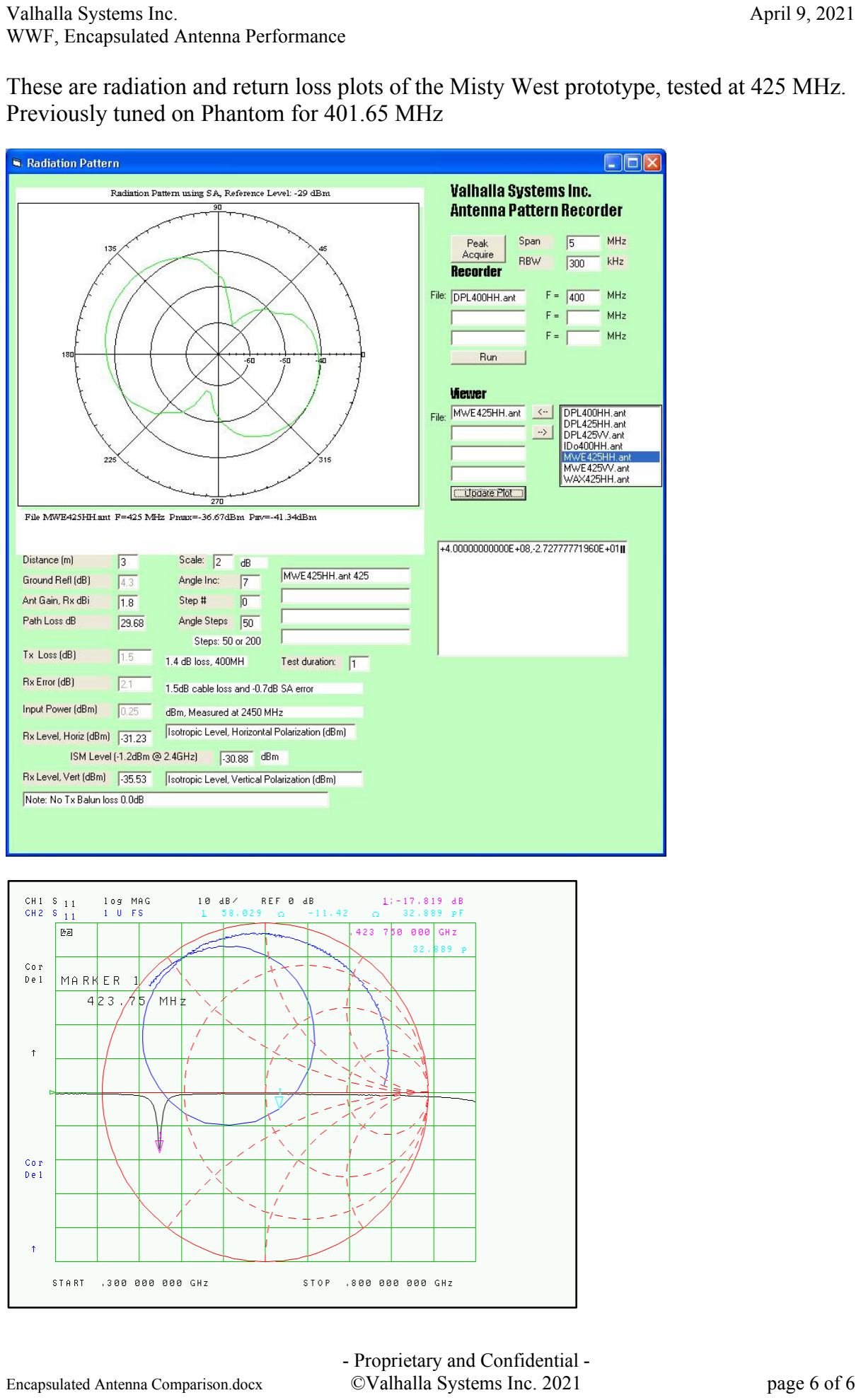
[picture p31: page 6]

Encapsulated Antenna Comparison.docx | ©Valhalla Systems Inc. 2021 | page 6 of 6

These are radiation and return loss plots of the Misty West prototype, tested at 425 MHz. Previously tuned on Phantom for 401.65 MHz

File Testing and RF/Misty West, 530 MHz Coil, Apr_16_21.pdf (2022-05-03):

Valhalla Systems Inc. | April 16, 2021
WWF, 530 MHz, Hybrid Coil Radiator Construction

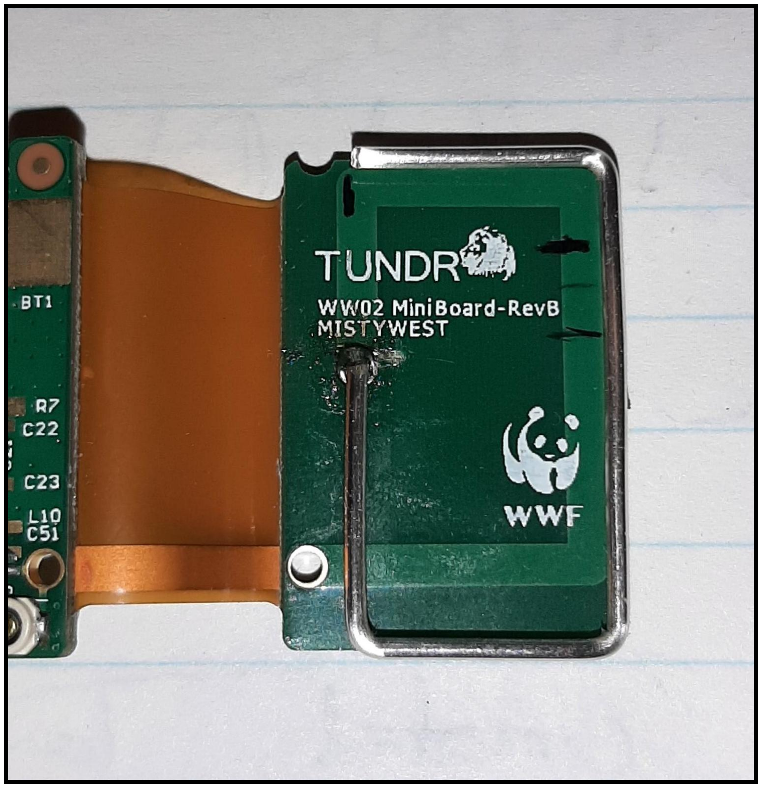
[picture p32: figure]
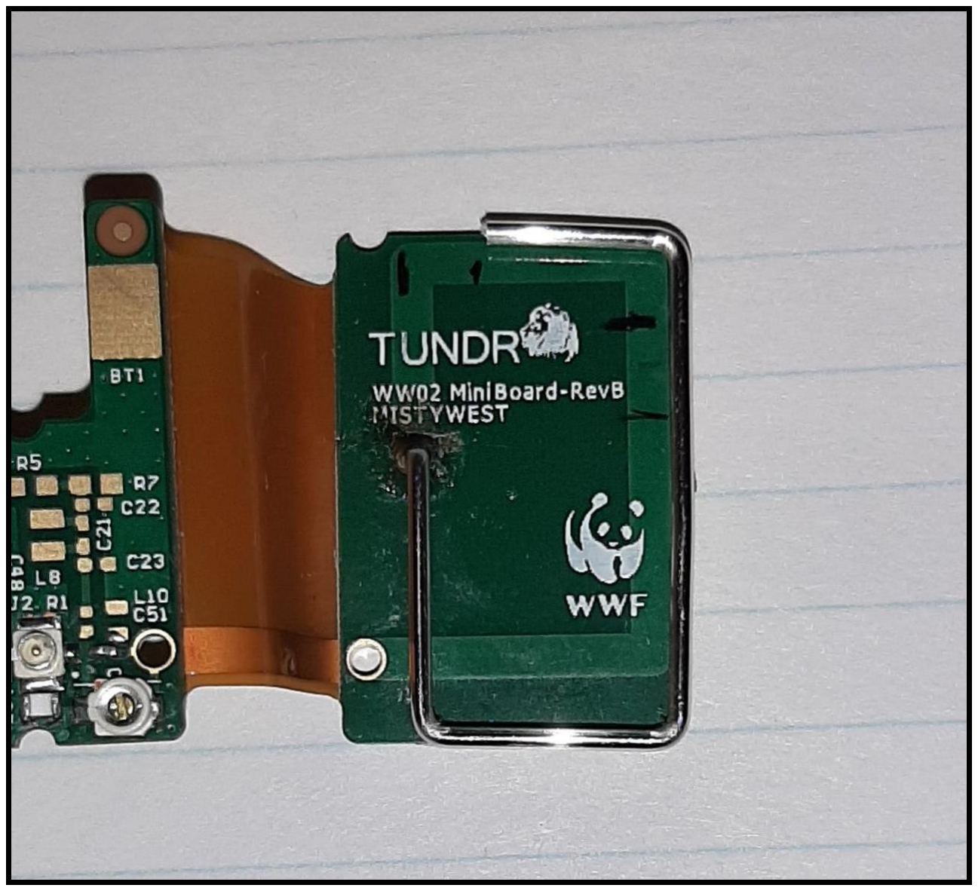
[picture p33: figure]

- Proprietary and Confidential -

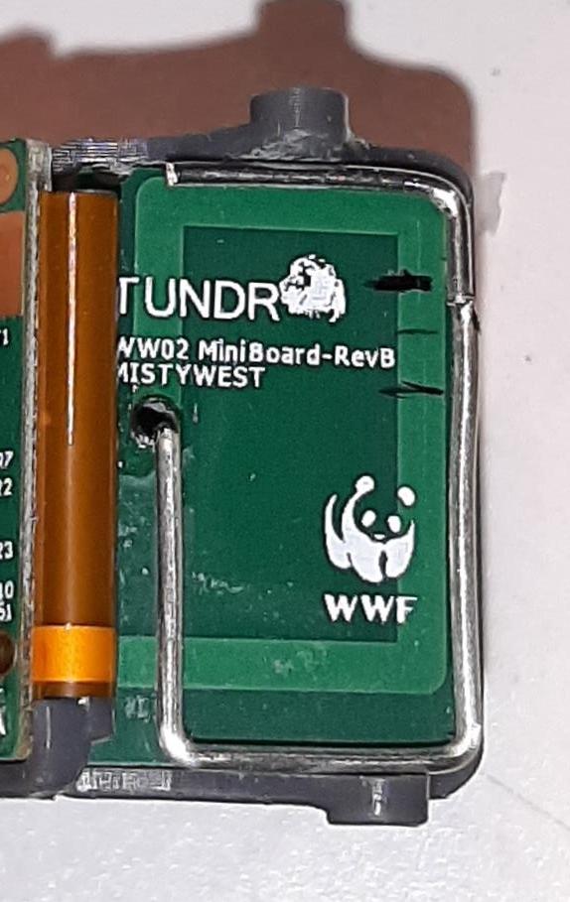
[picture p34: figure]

Misty West, 530 MHz Coil, Apr_16_21.doc | ©Valhalla Systems Inc. 2021 | page 1 of 4

General:
The resonator in the latest encapsulated unit was originally tuned to 586 MHz in air to achieve a 425 MHz target frequency after encapsulation. However, the measured resonant frequency was 465 MHz. The most plausible explanation is a lower dielectric constant of the encapsulant compared to IDEO’s original material. The deviation is significant and may indicate that there are fundamental differences in the encapsulation process, e.g. different materials.

An extension for the resonator was created, inserted into the encapsulant, and soldered to the existing resonator. The end of the resonator was within the encapsulant but should have terminated 15 mm from the right board edge, as shown. The resonance of this modified unit reduced to the target of 425 MHz.

A representative extension was created and attached to an existing 586 MHz prototype. The extension reduced the resonance to between 526 and 537 MHz.

Soldered Extension, 526.25 to 537.75 MHz | Solid Extension, 511.25 to 518.75 MHz

Solid Extension, 523.25 to 535 MHz, 12 mm

A Solid wire version of the resonator was created and installed onto the prototype but was found to resonate too low in frequency. The length was reduced such that the coil terminated 12mm from the right board edge which was found to duplicate the range of the soldered extension. Note: when installed in the mount the end of the resonator aligns with the mark.

Valhalla Systems Inc. | April 16, 2021
WWF, 530 MHz, Hybrid Coil Radiator Construction


Misty West, 530 MHz Coil, Apr_16_21.doc | ©Valhalla Systems Inc. 2021 | page 2 of 4

Return loss and range performance,

The construction of the Hybrid Coil is described. The return loss performance at the maximum and minimum capacitance is shown with L9 is installed as 5.6nH for consistency with previous measurements. The matching component on the board is to be 6.8nH and will improved the return loss.

Max Capacitance, 523.75 MHz | Min Capacitance, 525 MHz

Valhalla Systems Inc. | February 17, 2021
WWF, 586 MHz, Hybrid Coil Radiator Construction


Misty West, 530 MHz Coil, Apr_16_21.doc | ©Valhalla Systems Inc. 2021 | page 3 of 4

Modifications:

PCB Radiator Removal:
Sever the PCB radiator at the position shown. Two cuts through the radiator ~1.5mm apart with the copper between removed.

Hybrid Coil Construction:
Starting with a straightened, 9 cm, length of #16 AWG wire.

Initial Bend:
This forms the connection to the PCB. The tail needs to be long enough to allow soldering into the via on the PCB but not so long that it extends through the PCB once soldered. The coil is spaced 1.6mm above the PCB so a length of ~2.5mm is desired. As a spacer is used for positioning this length is critical only for mechanical attachment.

First, second and third bends:
The coil is bent using the edge of the PCB as a length gauge. Positioning the pliers at the edge results in the outside of the bent section falling within the confines of the PCB (or at least very close). This is to keep the resonator within the confines of the mount.

Valhalla Systems Inc. | February 17, 2021
WWF, 586 MHz, Hybrid Coil Radiator Construction


Misty West, 530 MHz Coil, Apr_16_21.doc | ©Valhalla Systems Inc. 2021 | page 4 of 4

Vertical Position:
The coil is clamped to the resonator assembly using a scrap piece of PCB for consistent vertical spacing (1.6mm). The coil is manually aligned with the edges of the PCB and then soldered. The coil is then trimmed to length, 12 mm from the right PCB edge.

Note: Clamping the assembly onto a second piece of scrap material will prevent solder flow through the via. This is to avoid mechanical conflicts with the mount.

Clamped, aluminum plate. | Soldered, Trimmed 15mm | Soldered, Trimmed, 12mm

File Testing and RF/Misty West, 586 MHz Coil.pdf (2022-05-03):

Valhalla Systems Inc. | February 17, 2021
WWF, 586 MHz, Hybrid Coil Radiator Construction


- Proprietary and Confidential -


Misty West, 586 MHz Coil.doc | ©Valhalla Systems Inc. 2021 | page 1 of 2

General:
The resonance of the PCB radiator alone resulted in poor performance compared to the discrete coil. The end of the coil was replaced with a short coil as a compromise between performance and construction and is referred to as the 'Hybrid Coil".

A phantom and paraffin wax were used to estimate the loading effects of the animal and the encapsulant. The presence of the animal resulted in a shift of 425 to 400 MHz while the encapsulant resulted in a 23% drop in wax and an estimated 27% drop if urethane is used. In summary, a resonant frequency of 585 MHz is estimated to result in operation of 400 MHz after encapsulation and when placed on the animal.

The construction of the Hybrid Coil is described. The return loss performance at the maximum and minimum capacitance is shown. L9 is installed as 5.6nH.

Max Capacitance, 586.25 MHz | Min Capacitance, 601.85 MHz

Modifications:

PCB Radiator Removal:
Sever the PCB radiator at the position shown. Two cuts through the radiator ~1.5mm apart with the copper between removed.

Valhalla Systems Inc. | February 17, 2021
WWF, 586 MHz, Hybrid Coil Radiator Construction


- Proprietary and Confidential -


Misty West, 586 MHz Coil.doc | ©Valhalla Systems Inc. 2021 | page 2 of 2

Hybrid Coil Construction:
Starting with a straightened, 6 cm, length of #16 AWG wire.

Initial Bend:
This forms the connection to the PCB. The tail needs to be long enough to allow soldering into the via on the PCB but not so long that it extends through the PCB once soldered. The coil is spaced 1.6mm above the PCB so a length of ~2.5mm is desired. As a spacer is used for positioning this length is critical only for mechanical attachment.

First and Second Bends:
The coil is bent using the edge of the PCB as a length gauge. Positioning the pliers at the edge results in the outside of the bent coil falling within the confines of the PCB due to the bend radius of the wire (or very close).

Vertical Position:
The coil is clamped to the resonator assembly using a scrap piece of PCB for consistent vertical spacing (1.6mm). The coil is manually aligned with the edges of the PCB and then soldered. The coil is then trimmed to length, 8mm from the top PCB edge.

Note: Clamping the assembly onto a second piece of scrap material will prevent solder flow through the via. This is to avoid mechanical conflicts with the mount.

Clamped | Soldered | Trimmed

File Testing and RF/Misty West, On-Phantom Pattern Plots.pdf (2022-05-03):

Valhalla Systems Inc. | April 21, 2021
WWF, On-Phantom Pattern Plots


- Proprietary and Confidential -
Misty West, On-Phantom Pattern Plots.doc | ©Valhalla Systems Inc. 2021 | page 1 of 4

General:
The Misty West Encapsulated (MWE_21) prototype was mounted to the phantom. The resonance was verified and radiation patterns measured.

MWE_Apr_21 Prototype mounted on phantom, resonance at 400 MHz. Un-mounted resonance was ~ 420 MHz.

Radiation Pattern Plots:
The presence of the phantom produces a frequency shift in resonance as well as introducing loss and affecting the radiation pattern. These plots were taken to characterize the resulting emissions.

On loss, the difference in resonant freqeuncies makes performance comparision difficult but the peak levels phantom/nophantom appear to be within a couple of dB. A moderate increase in loss is assumed.

The radiation pattern is skyward from the transmitter side of the animal and slightly towards the rear. The ½ power beamwidth is also relatively wide (> 45 degrees) so the system should not be overly directional.


Misty West, On-Phantom Pattern Plots.doc | ©Valhalla Systems Inc. 2021 | page 2 of 4

Horiztonal Pattern,
The assembly was positioned as shown in the images before the patterns were measured. The 0 degree orientation of the plots corresponds to the right side of the image and the rotation is clockwise.
The unit shown in measurement orienation. | The unit shown on measurement stand.

This characterizes the emissions levels around the animal. The 0 degree orientation is the right side, 90 degrees is the rear, 180 degrees is the left side, and 270 degrees would be the nose.

Main lobe direction is looking slightly back from the ear.


Misty West, On-Phantom Pattern Plots.doc | ©Valhalla Systems Inc. 2021 | page 3 of 4

Axial Pattern,
The assembly was positioned as shown in the images before the patterns were measured. The 0 degree orientation of the plots corresponds to the right side of the image and the rotation is clockwise.
The unit shown in measurement orienation. | The unit shown on measurement stand.

This characterizes the emissions levels around the axis of the animal. The 0 degree orientation is looking at the back side, 90 degrees is the nose, 180 degrees is underneath, and 270 degrees would be the rear.

Main lobe direction is up from the animal’s back, pointing skywards.


Misty West, On-Phantom Pattern Plots.doc | ©Valhalla Systems Inc. 2021 | page 4 of 4

Profile Pattern,
The assembly was positioned as shown in the images before the patterns were measured. The 0 degree orientation of the plots corresponds to the right side of the image and the rotation is clockwise.

Note: The receive antenna was vertical for these measurements to match the orientation of the unit.

The unit shown in measurement orienation. | The unit shown on measurement stand

This characterizes the emissions levels around the middle of the animal. The 0 degree orientation is looking at the right ear, 90 degrees is the back, 180 degrees is the left side, and 270 degrees would be under the animal.

Main lobe direction is out from the transmitter or from the right side of the animal.

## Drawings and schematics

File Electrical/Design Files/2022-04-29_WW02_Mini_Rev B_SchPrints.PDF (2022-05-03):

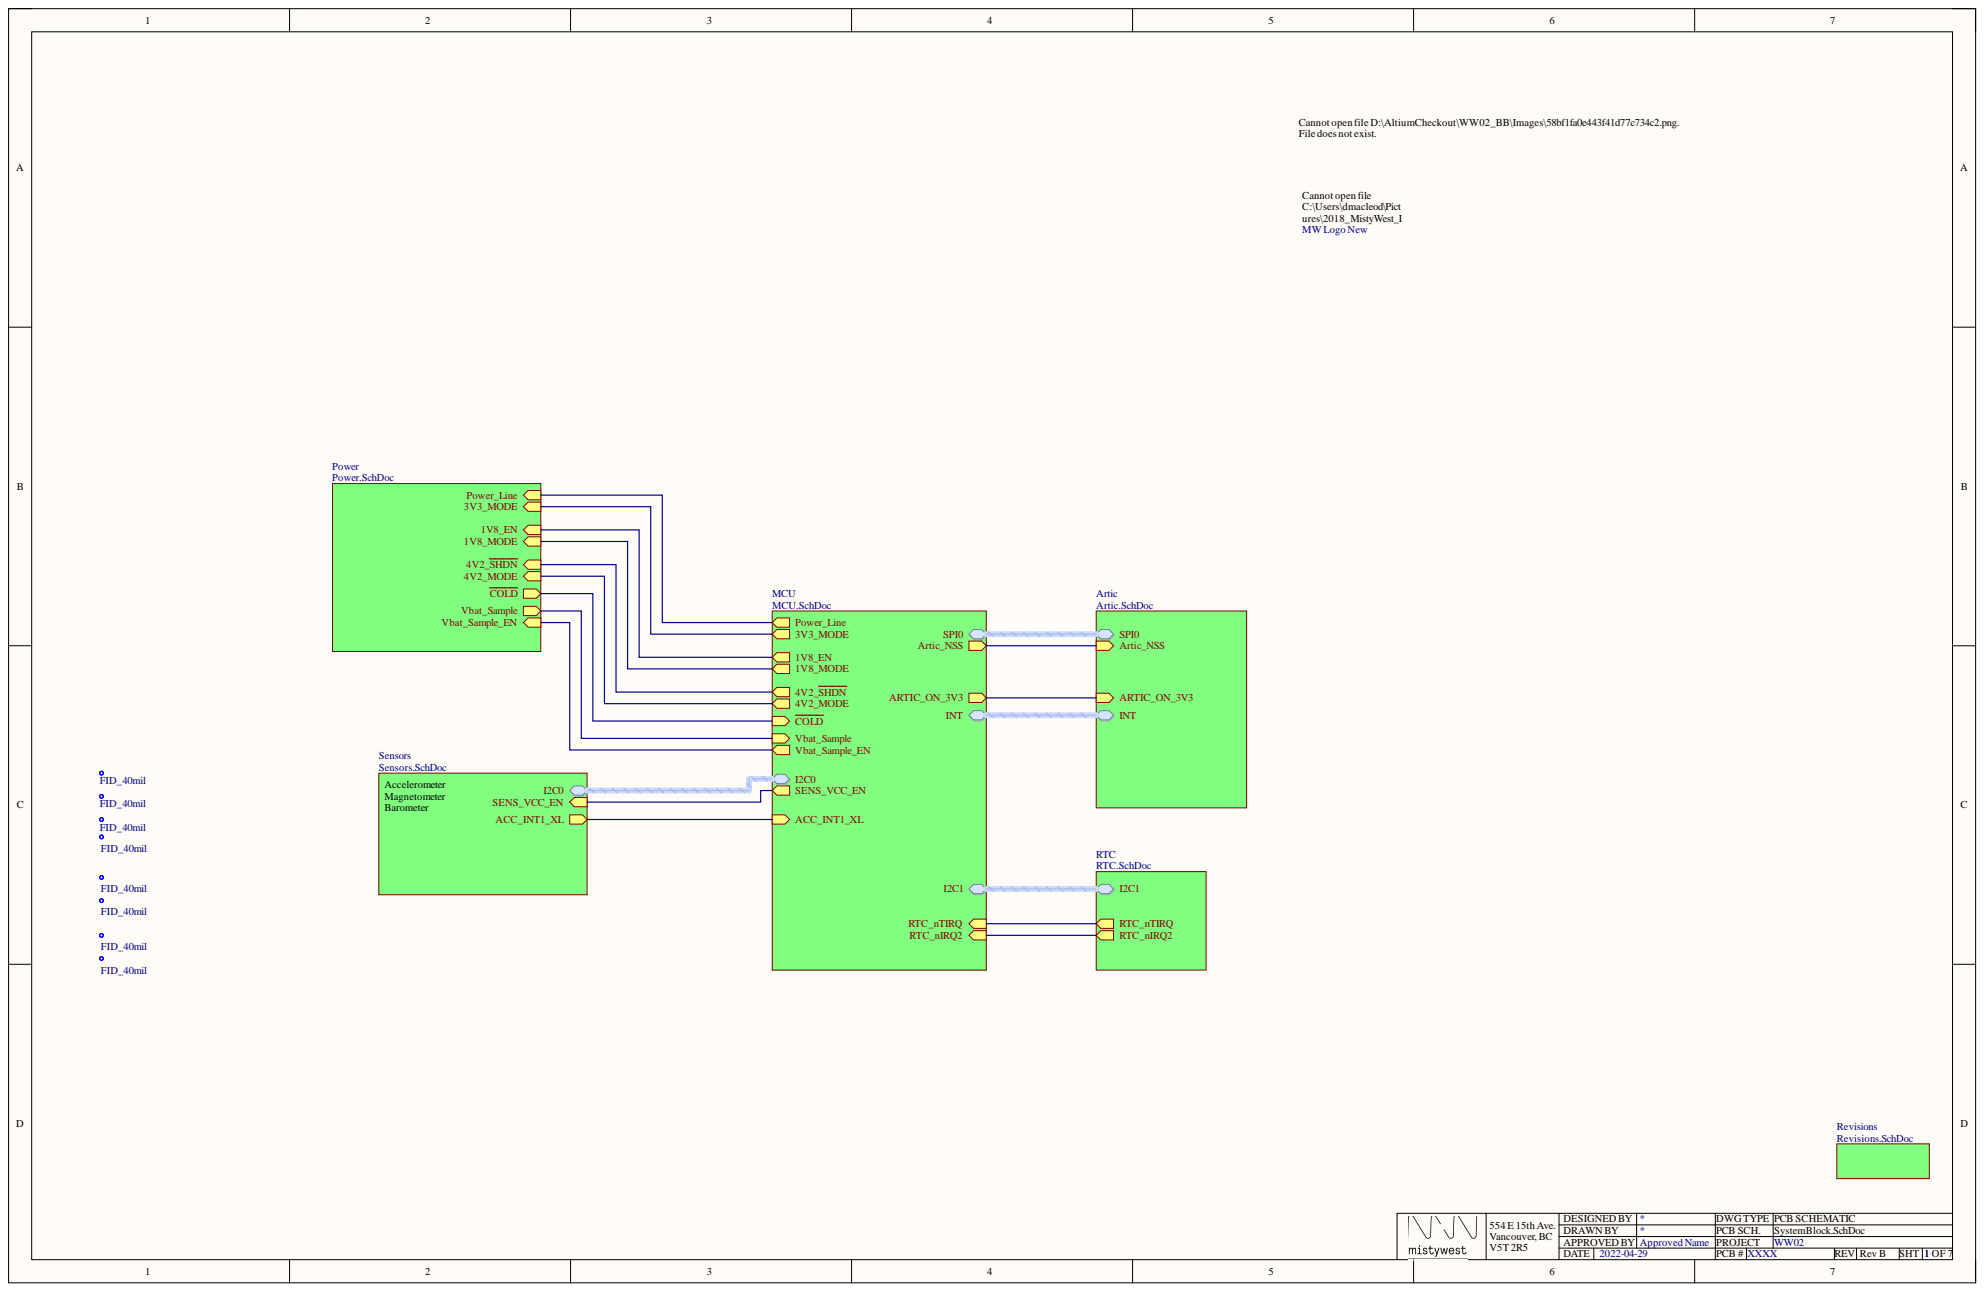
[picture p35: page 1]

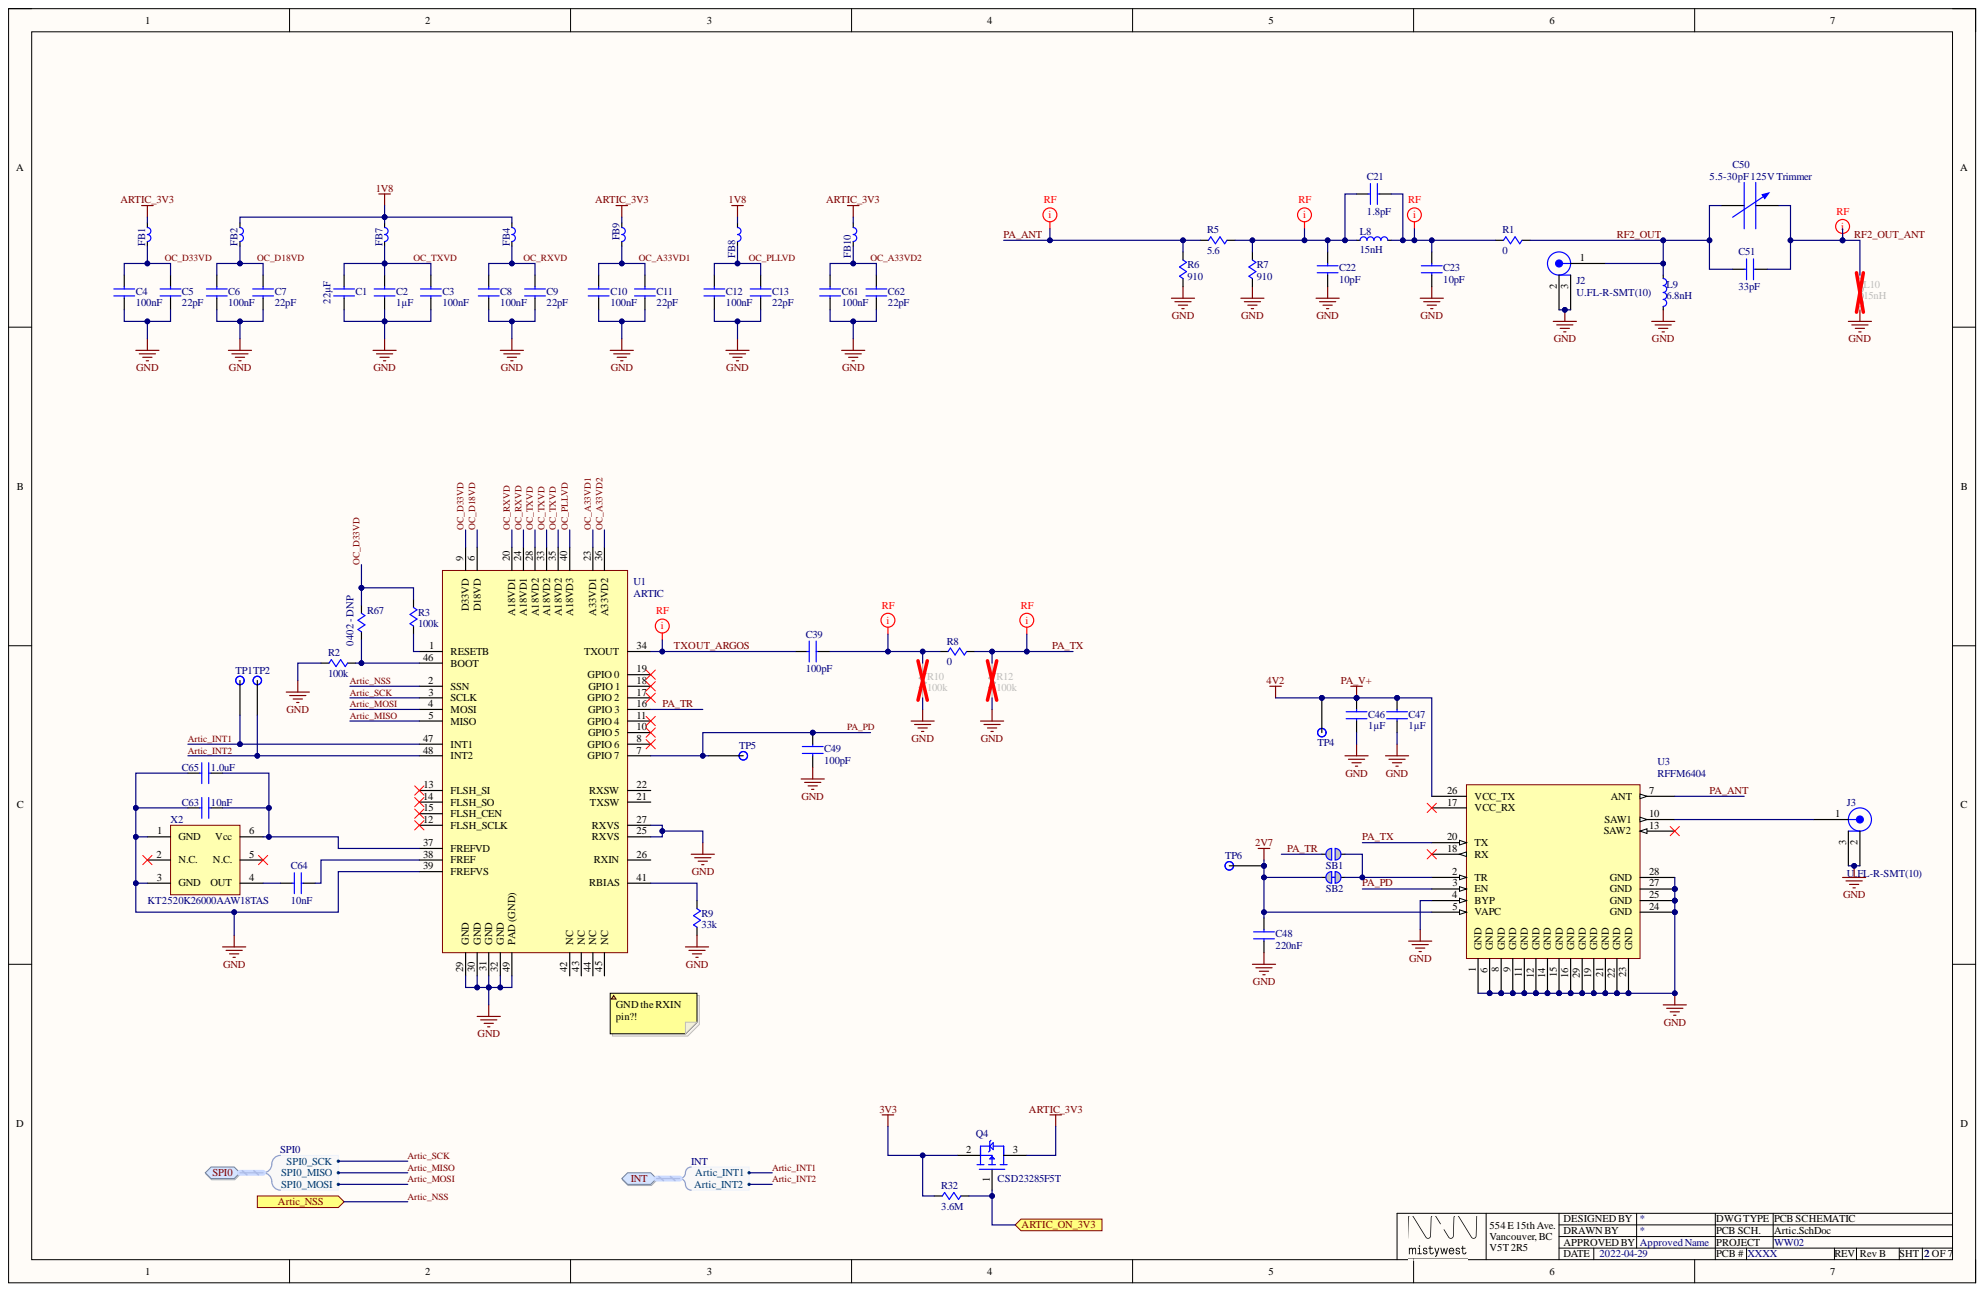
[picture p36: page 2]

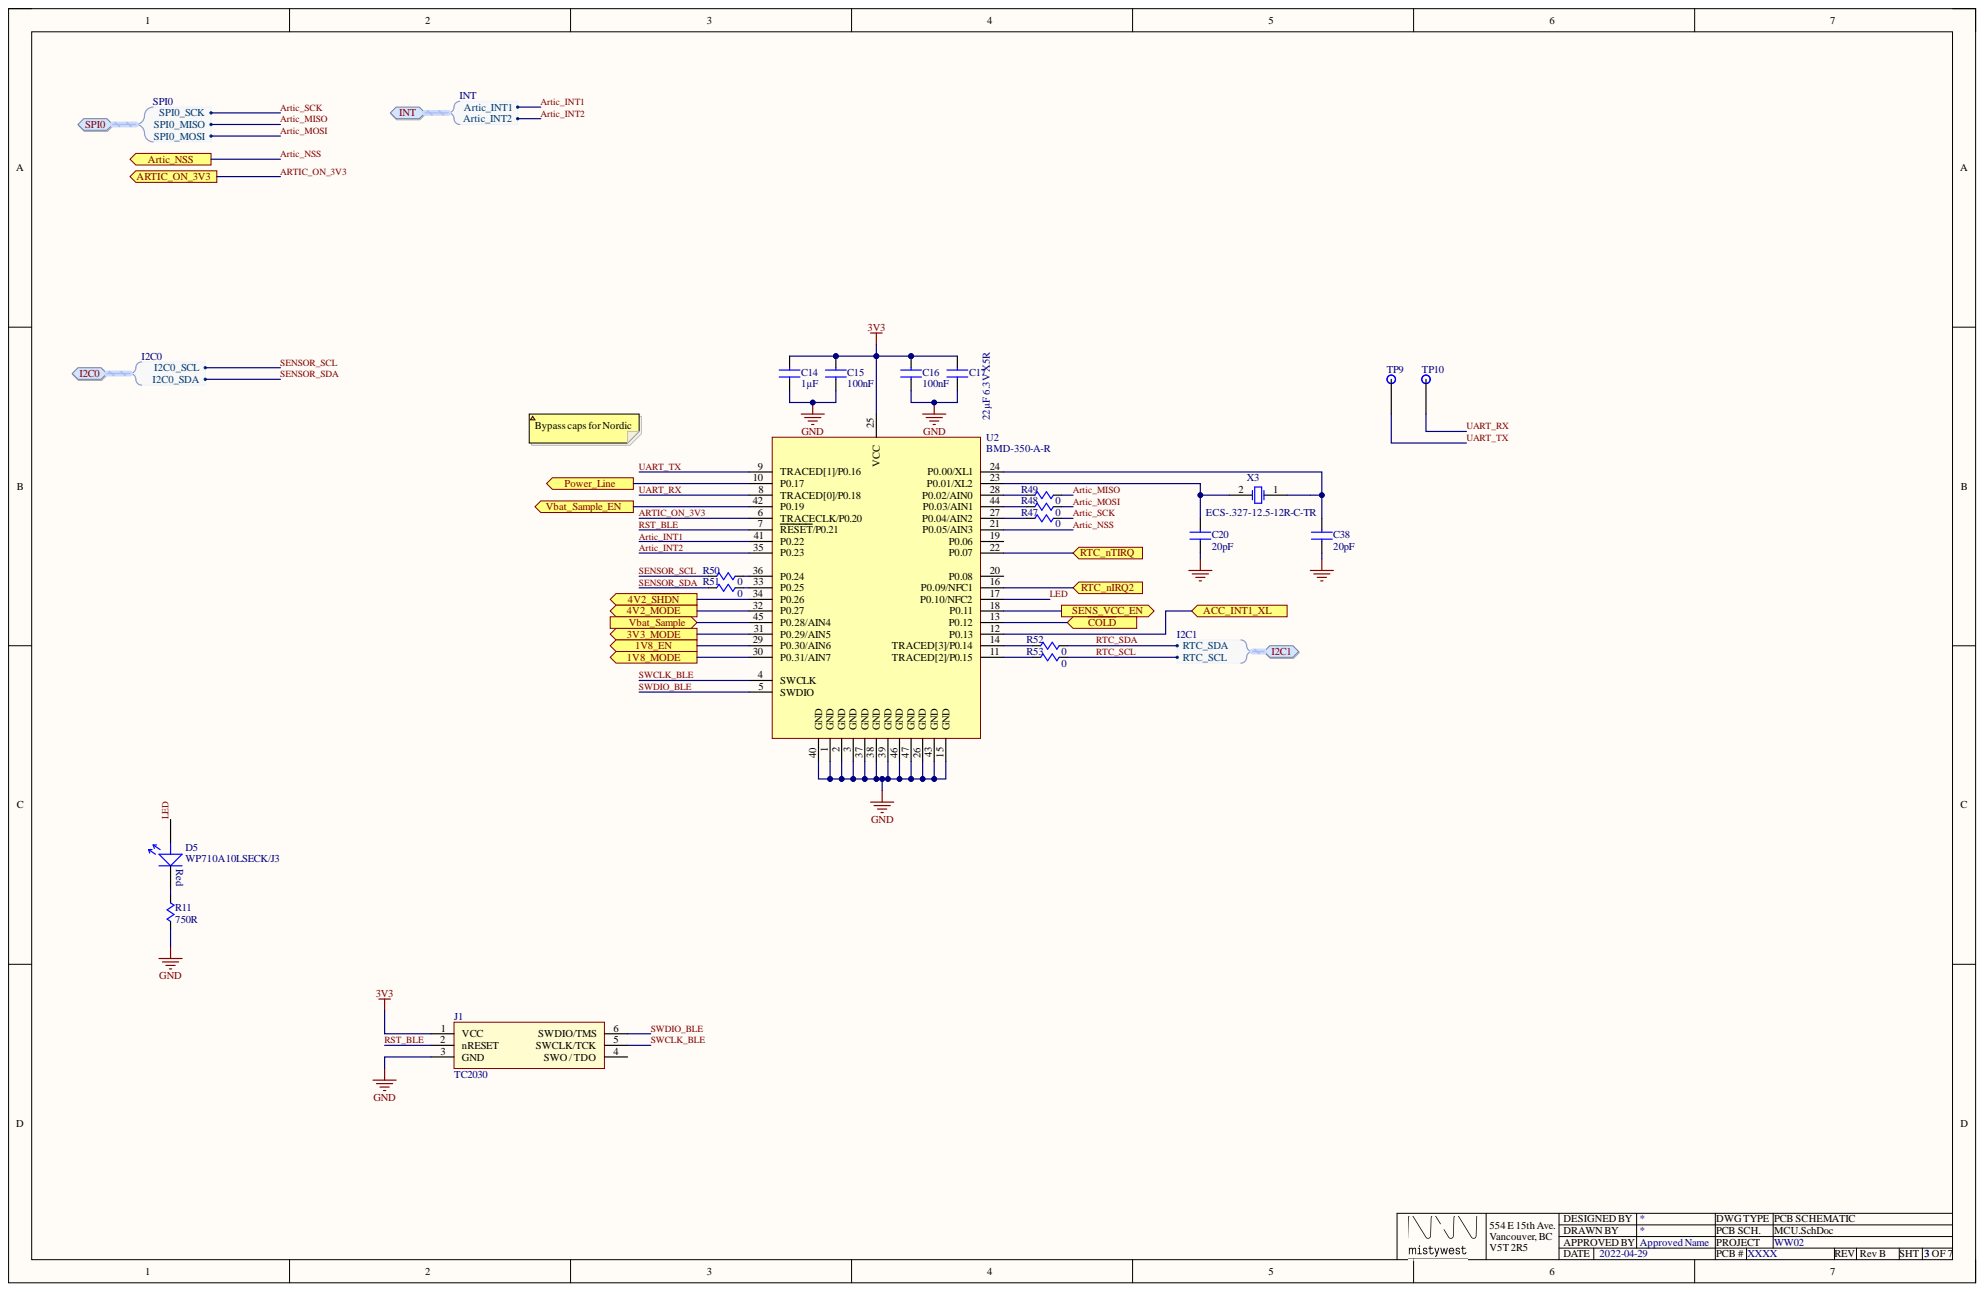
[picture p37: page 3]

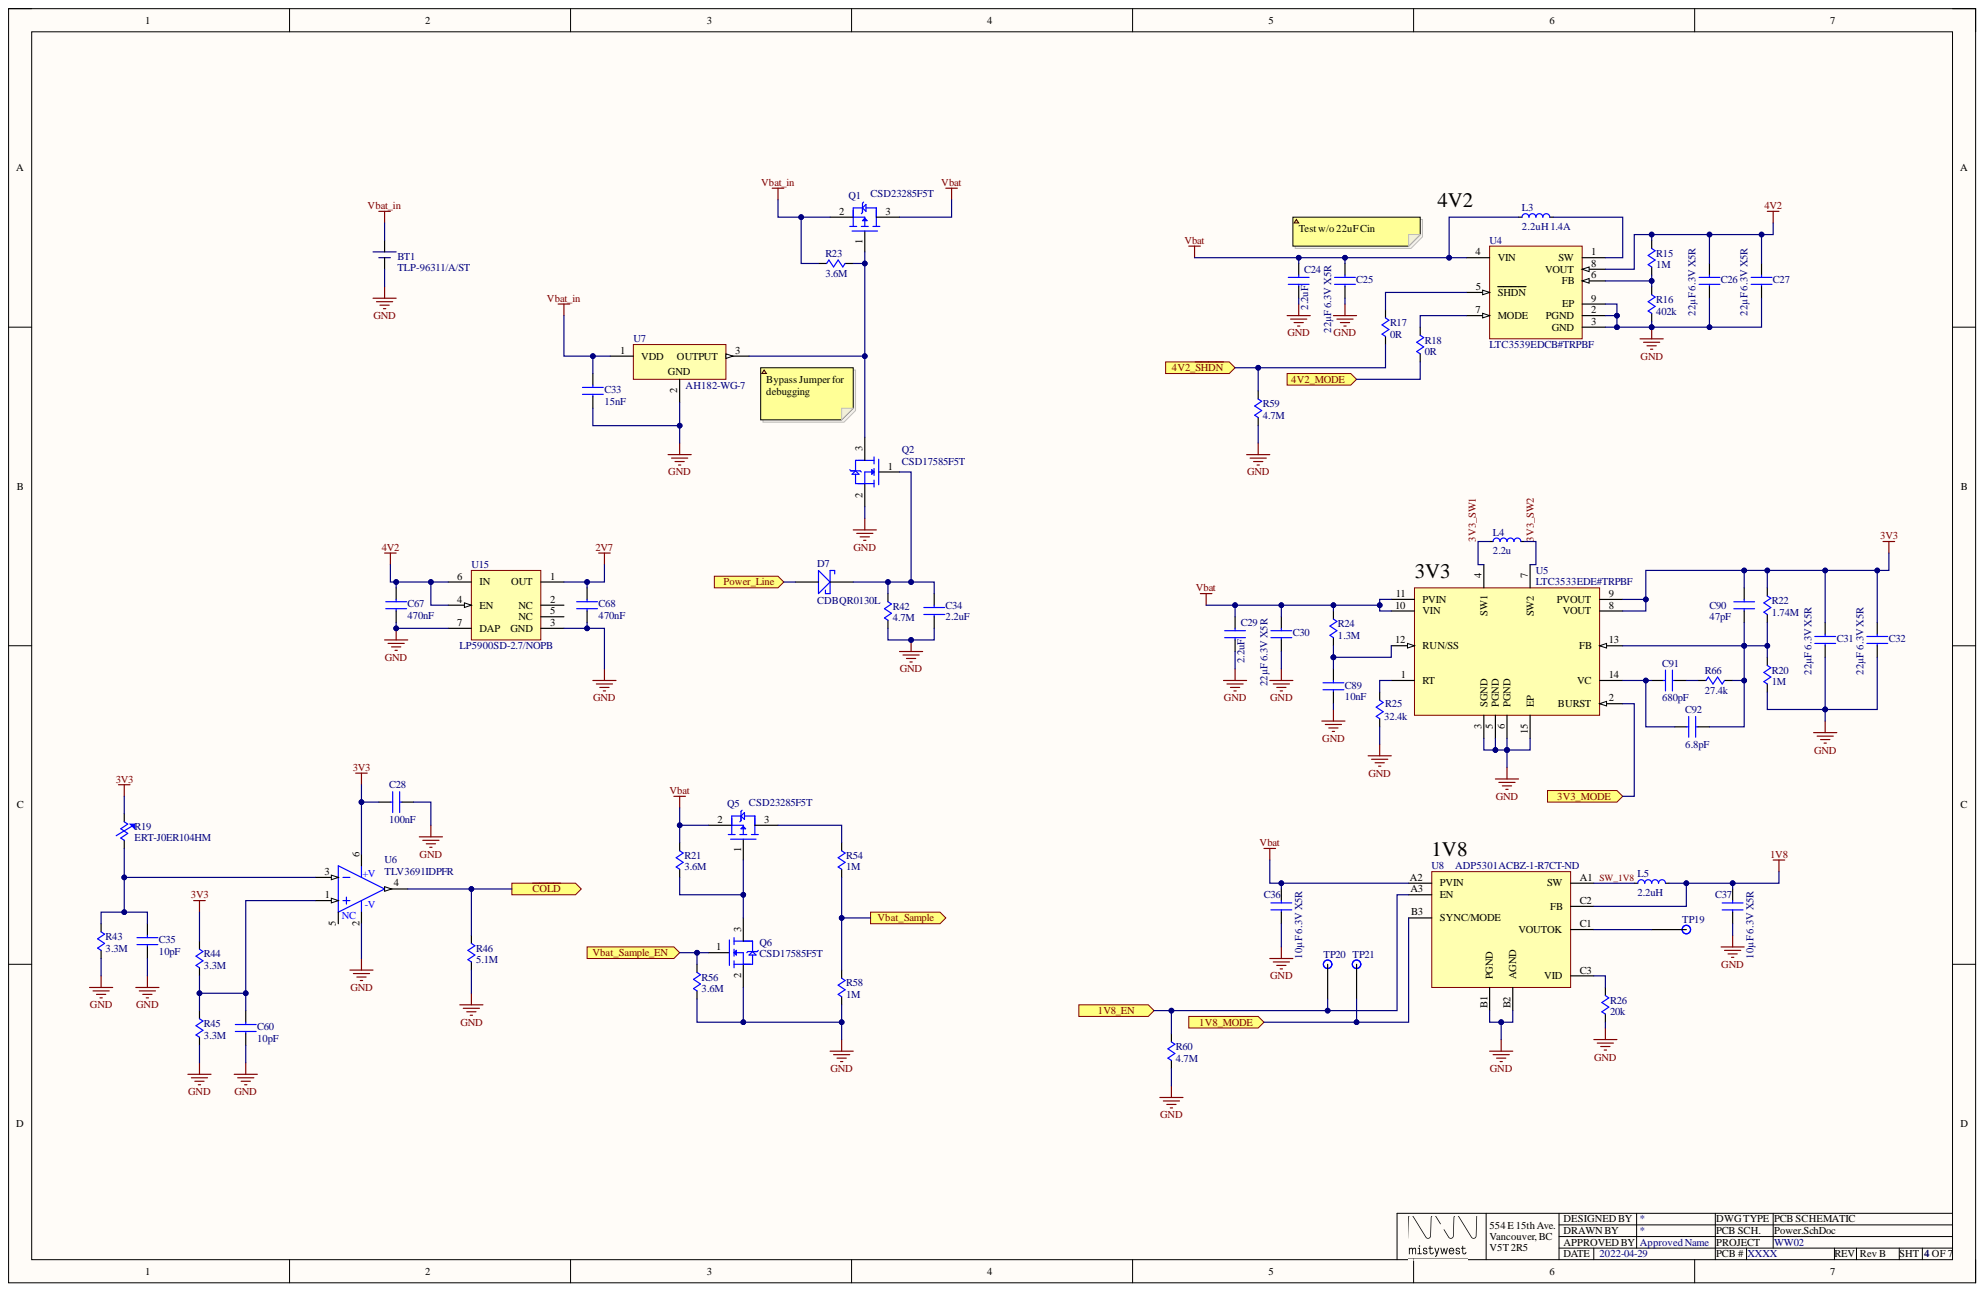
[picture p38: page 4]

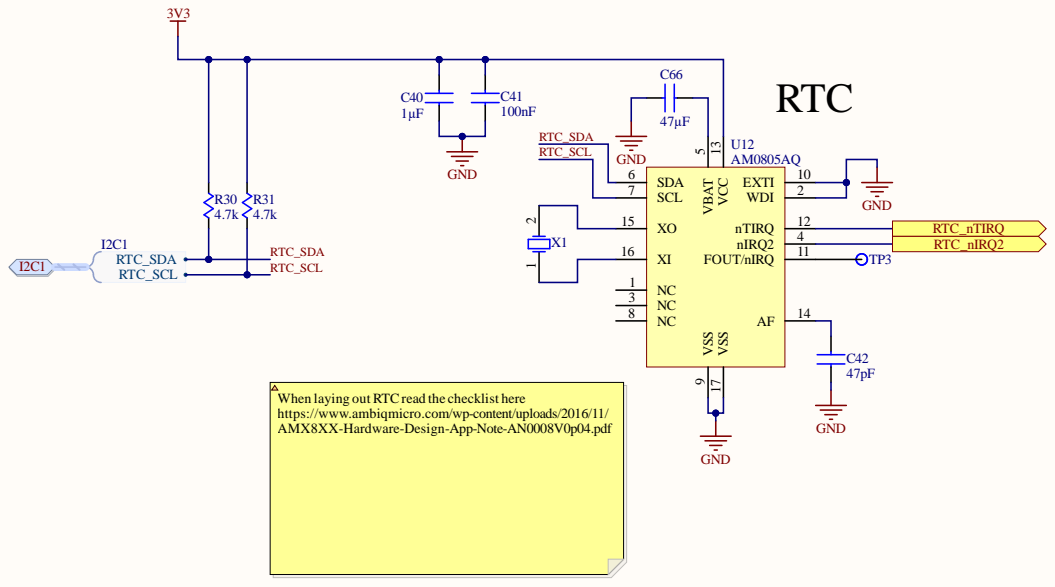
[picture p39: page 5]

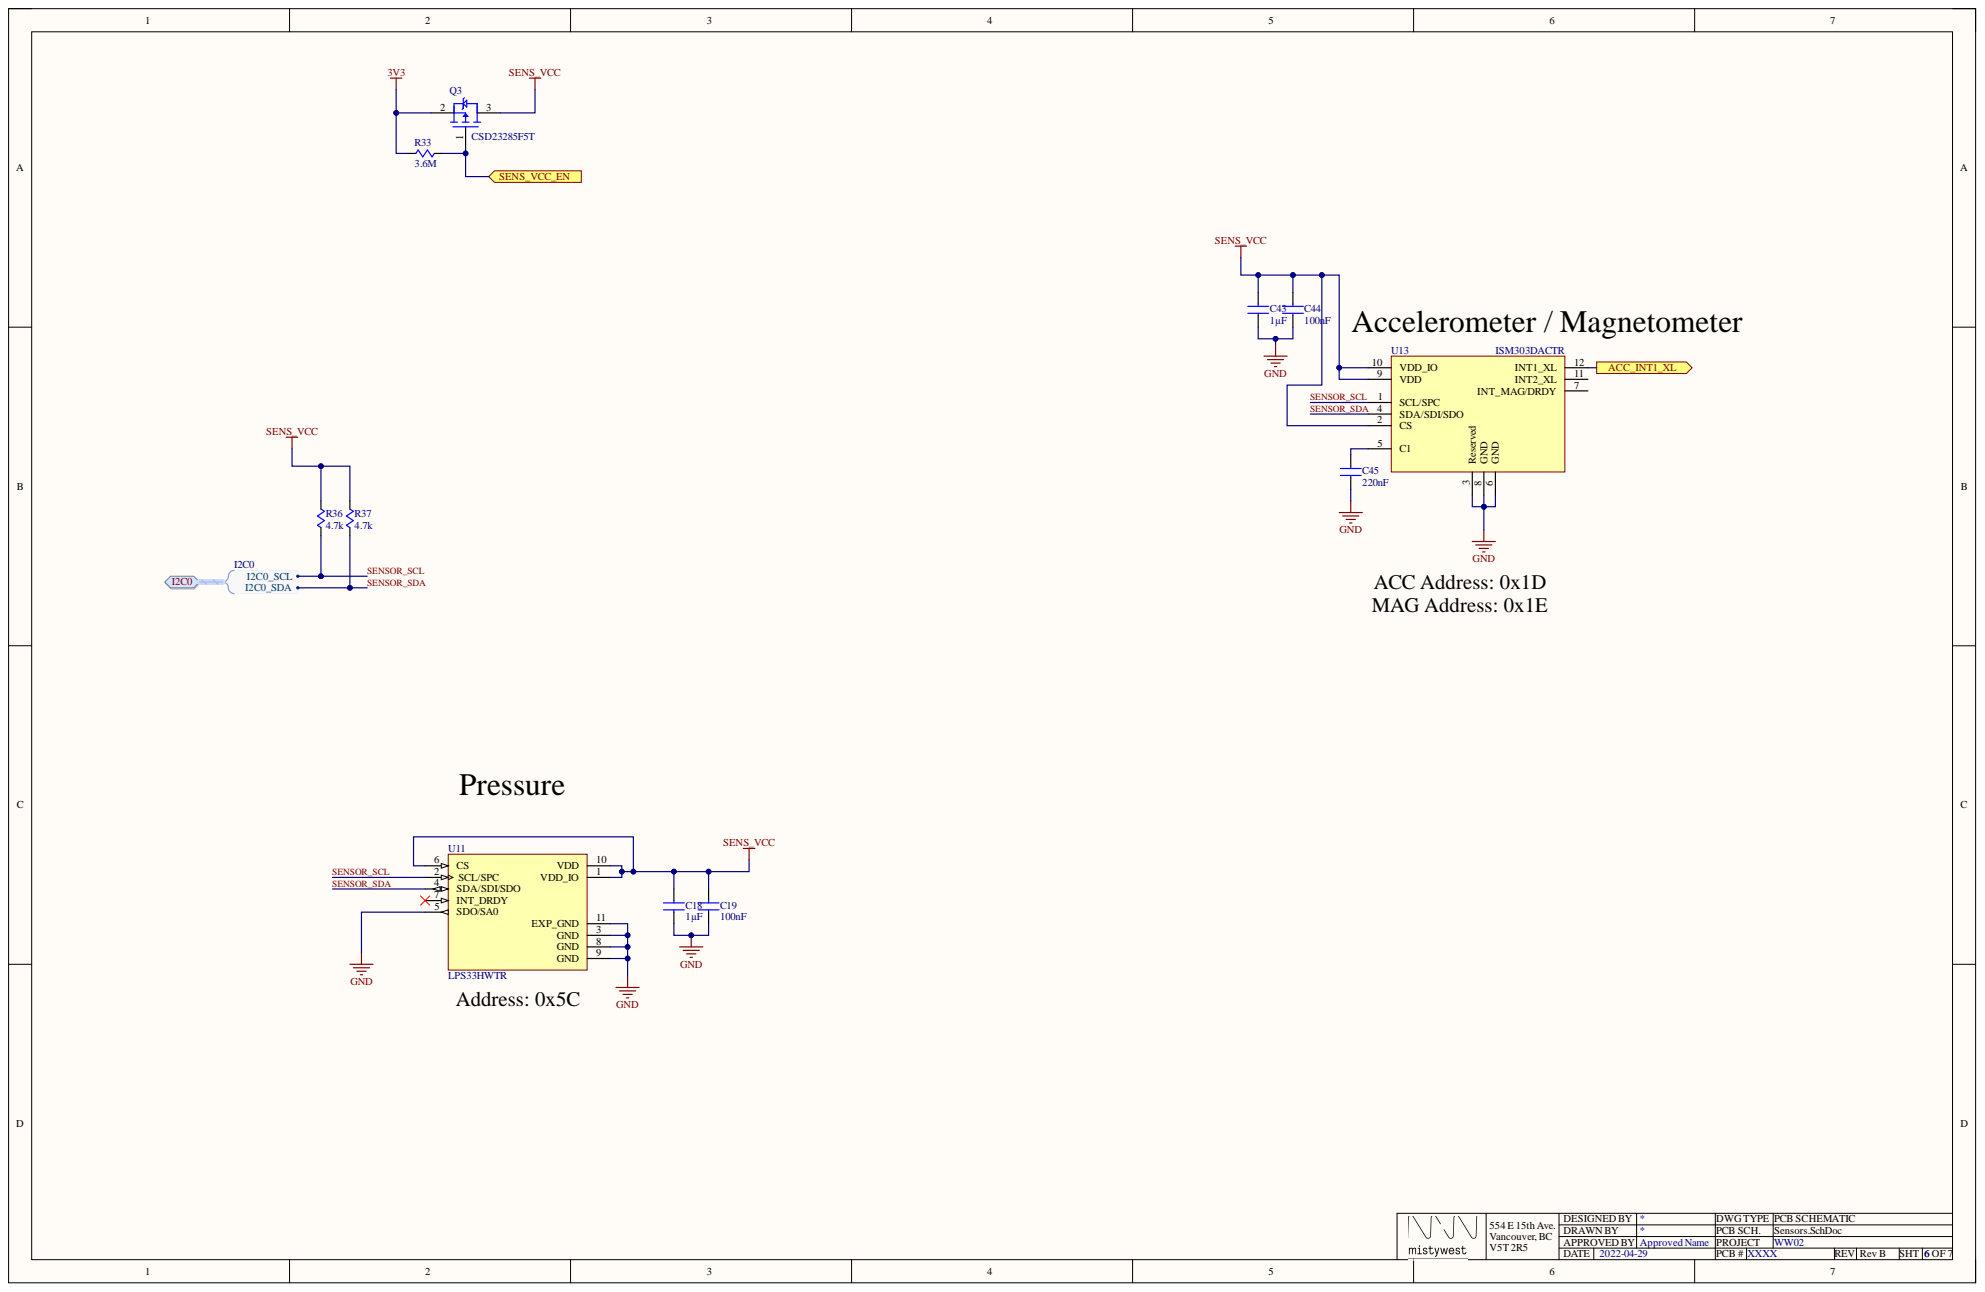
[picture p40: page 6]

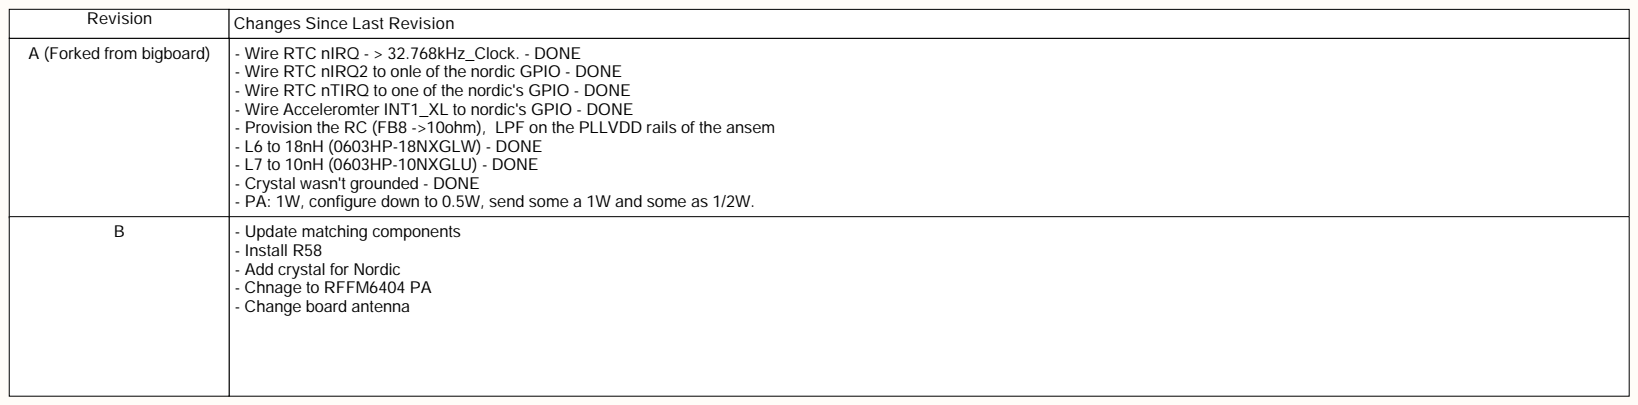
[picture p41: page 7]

Revision | Changes Since Last Revision

A (Forked from bigboard) | - Wire RTC nIRQ - > 32.768kHz_Clock. - DONE - Wire RTC nIRQ2 to onle of the nordic GPIO - DONE - Wire RTC nTIRQ to one of the nordic's GPIO - DONE - Wire Acceleromter INT1_XL to nordic's GPIO - DONE - Provision the RC (FB8 ->10ohm), LPF on the PLLVDD rails of the ansem - L6 to 18nH (0603HP-18NXGLW) - DONE - L7 to 10nH (0603HP-10NXGLU) - DONE - Crystal wasn't grounded - DONE - PA: 1W, configure down to 0.5W, send some a 1W and some as 1/2W.

B | - Update matching components - Install R58 - Add crystal for Nordic - Chnage to RFFM6404 PA - Change board antenna

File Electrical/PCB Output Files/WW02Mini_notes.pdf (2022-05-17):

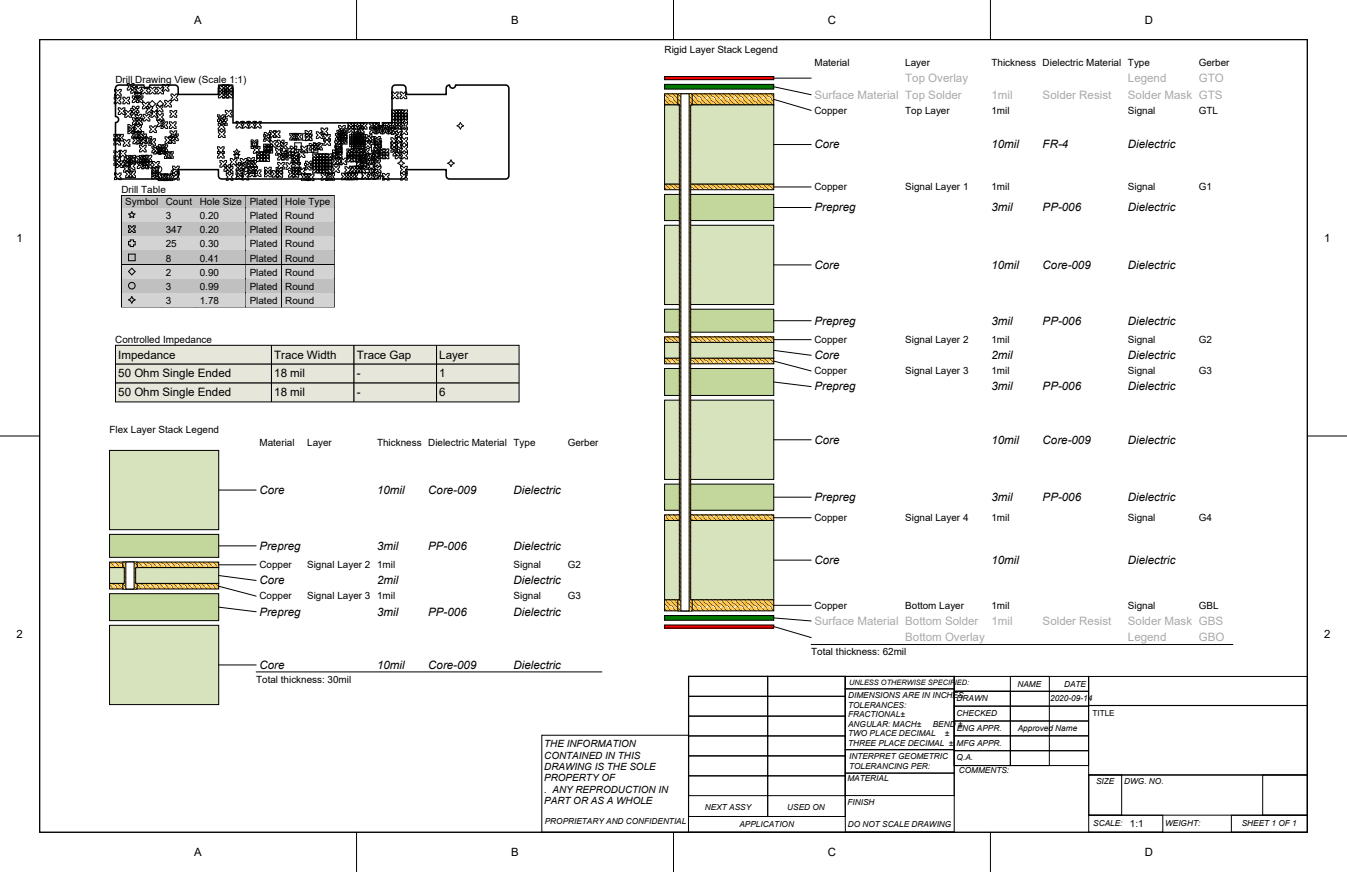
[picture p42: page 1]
Drill Table; DWG. NO.; COMMENTS:; FINISH; APPLICATION; DO NOT SCALE DRAWING; NEXT ASSY; USED ON; ANGULAR: MACH±; BEND ±; NAME; DATE; TITLE; MFG APPR.; ENG APPR.; Approved Name; CHECKED; DRAWN; SCALE:; WEIGHT:; SHEET 1 OF 1; SIZE; Trace Width 18 mil 18 mil; Trace Gap - -; Layer 1 6; Material; Layer; Thickness Dielectric Material Type; Gerber; Top Overlay; Legend; GTO; Surface Material Top Solder; 1mil; Solder Resist; Solder Mask GTS; Copper; Top Layer; Signal; GTL; Core; 10mil; Dielectric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

Rigid Layer Stack Legend

Drill Drawing View (Scale 1:1)

Symbol | Count | Hole Size | Plated | Hole Type

3 | 0.20 | Plated | Round
347 | 0.20 | Plated | Round
25 | 0.30 | Plated | Round
8 | 0.41 | Plated | Round
2 | 0.90 | Plated | Round
3 | 0.99 | Plated | Round
3 | 1.78 | Plated | Round

Controlled Impedance
Impedance
50 Ohm Single Ended

Flex Layer Stack Legend

UNLESS OTHERWISE SPECIFIED:
DIMENSIONS ARE IN INCHES
TOLERANCES:
FRACTIONAL±
TWO PLACE DECIMAL ±
THREE PLACE DECIMAL ±
INTERPRET GEOMETRIC
TOLERANCING PER:
MATERIAL

THE INFORMATION
CONTAINED IN THIS
DRAWING IS THE SOLE
PROPERTY OF
. ANY REPRODUCTION IN
PART OR AS A WHOLE

PROPRIETARY AND CONFIDENTIAL

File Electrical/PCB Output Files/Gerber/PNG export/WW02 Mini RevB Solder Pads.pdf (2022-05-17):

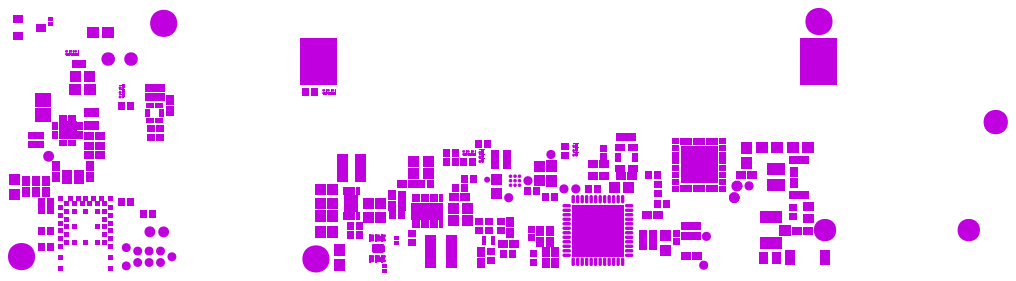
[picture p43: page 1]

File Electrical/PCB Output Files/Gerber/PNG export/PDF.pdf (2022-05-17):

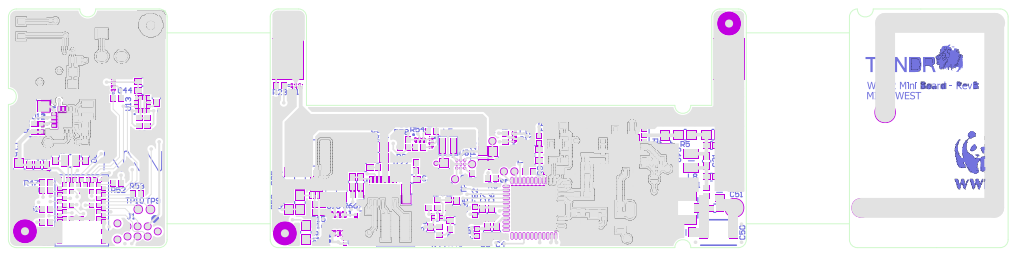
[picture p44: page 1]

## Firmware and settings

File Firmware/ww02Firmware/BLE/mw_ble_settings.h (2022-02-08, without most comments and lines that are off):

#define BLE_MW_BLE_SETTINGS
#include "project_settings.h"
#if BLE_PERIPHERAL_THREAD_ENABLED
#define DEVICE_NAME                         "WWF Tracker"
#elif BLE_CENTRAL_THREAD_ENABLED
#define DEVICE_NAME                         "MW_Central_device"
#else
#define DEVICE_NAME                         "MW_device"
#endif
#define MW_GET_ADV_TIMEOUT(ADV_TIMEOUT) ADV_TIMEOUT * 100
#define IS_SRVC_CHANGED_CHARACT_PRESENT 		1
#define CENTRAL_LINK_COUNT               		1
#define PERIPHERAL_LINK_COUNT            		1
#define MW_ADVERTISING_RADIO_TX							TX_PWR_ZERO_DB
#define MW_CONNECTED_RADIO_TX								TX_PWR_ZERO_DB
#define TX_PWR_ZERO_DB											0
#define TX_PWR_FOUR_DB											4
#define MW_ULTRA_FAST_ADV_INTERVAL          32
#define MW_ULTRA_FAST_ADV_TIMEOUT           MW_GET_ADV_TIMEOUT(2)
#define MW_FAST_ADV_INTERVAL								80
#define MW_FAST_ADV_TIMEOUT									MW_GET_ADV_TIMEOUT(8)
#define MW_MED_ADV_INTERVAL				    			668
#define MW_MED_ADV_TIMEOUT									MW_GET_ADV_TIMEOUT(30 )
#define MW_SLOW_ADV_INTERVAL			    			2510
#define MW_SLOW_ADV_TIMEOUT			        		MW_GET_ADV_TIMEOUT(0)
#define DEFAULT_MIN_CONN_INTERVAL           MSEC_TO_UNITS(30, UNIT_1_25_MS)
#define DEFAULT_MAX_CONN_INTERVAL           MSEC_TO_UNITS(50, UNIT_1_25_MS)
#define DEFAULT_SLAVE_LATENCY               30
#define DEFAULT_CONN_SUP_TIMEOUT            MSEC_TO_UNITS(4000, UNIT_10_MS)
#define SLOW_MIN_CONN_INTERVAL              MSEC_TO_UNITS(450, UNIT_1_25_MS)
#define SLOW_MAX_CONN_INTERVAL              MSEC_TO_UNITS(495, UNIT_1_25_MS)
#define SLOW_SLAVE_LATENCY                  3
#define SLOW_CONN_SUP_TIMEOUT               MSEC_TO_UNITS(6000, UNIT_10_MS)
#define FAST_MIN_CONN_INTERVAL              MSEC_TO_UNITS(20, UNIT_1_25_MS)
#define FAST_MAX_CONN_INTERVAL              MSEC_TO_UNITS(40, UNIT_1_25_MS)
#define FAST_SLAVE_LATENCY                  5
#define FAST_CONN_SUP_TIMEOUT               MSEC_TO_UNITS(4000, UNIT_10_MS)
#define FIRST_CONN_PARAMS_UPDATE_DELAY      1000
#define NEXT_CONN_PARAMS_UPDATE_DELAY       3000
#define MAX_CONN_PARAMS_UPDATE_COUNT        2
#define SEC_PARAM_BOND                      1
#define SEC_PARAM_MITM                      0
#define SEC_PARAM_LESC                      0
#define SEC_PARAM_KEYPRESS                  0
#define SEC_PARAM_IO_CAPABILITIES           BLE_GAP_IO_CAPS_NONE
#define SEC_PARAM_OOB                       0
#define SEC_PARAM_MIN_KEY_SIZE              7
#define SEC_PARAM_MAX_KEY_SIZE              16
#define APP_BLE_OBSERVER_PRIO               3
#define APP_BLE_CONN_CFG_TAG                1
#define TARGET_PERIPHERAL_DEVICE_NAME       "Tile"
#define MW_BLE_SCAN_EXT_ADV_PACKETS         0
#define MW_BLE_SCAN_REPORT_INCOMPLETE_EVTS  0
#define MW_BLE_SCAN_ACTIVE_SCANNING         1
#define MW_BLE_SCAN_FILTER_POLICY           BLE_GAP_SCAN_FP_ACCEPT_ALL
#define MW_BLE_SCAN_BUFFER                  31
#define MW_BLE_SCAN_NAME_MAX_LEN            32
#define MW_BLE_SCAN_SHORT_NAME_MAX_LEN      50
#define MW_BLE_SCAN_SCAN_WINDOW             80
#define MW_BLE_SCAN_SCAN_INTERVAL           160
#define MW_BLE_SCAN_SCAN_DURATION           1000
#define MW_BLE_SCAN_ALL_CHANNELS            {0, 0, 0, 0, 0 }
#define MW_BLE_SCAN_MIN_CONNECTION_INTERVAL 7.5
#define MW_BLE_SCAN_MAX_CONNECTION_INTERVAL 30
#define MW_BLE_SCAN_SLAVE_LATENCY           0
#define MW_BLE_SCAN_SUPERVISION_TIMEOUT     4000
#define MW_BLE_SCAN_SCAN_PHY                  BLE_GAP_PHY_AUTO
#define MW_BLE_SCAN_DEFAULT_PARAMETERS                                \
{                                                                     \
    .extended               = MW_BLE_SCAN_EXT_ADV_PACKETS,            \
    .report_incomplete_evts = MW_BLE_SCAN_REPORT_INCOMPLETE_EVTS,     \
    .active                 = MW_BLE_SCAN_ACTIVE_SCANNING,            \
    .filter_policy          = MW_BLE_SCAN_FILTER_POLICY,              \
    .scan_phys              = MW_BLE_SCAN_SCAN_PHY,                   \
    .interval               = MW_BLE_SCAN_SCAN_INTERVAL,              \
    .window                 = MW_BLE_SCAN_SCAN_WINDOW,                \
    .timeout                = MW_BLE_SCAN_SCAN_DURATION,              \
    .channel_mask           = MW_BLE_SCAN_ALL_CHANNELS                \
}                                                                     \
#if ( (NRF_SDH_CLOCK_LF_SRC == 1) && (NRF_SDH_CLOCK_LF_RC_CTIV || NRF_SDH_CLOCK_LF_RC_CTIV ) )
#warning Incorrect LFCLK Settings.  NRF_SDH_CLOCK_LF_RC_CTIV and NRF_SDH_CLOCK_LF_RC_CTIV should be set to zero
#endif
#define OPCODE_LENGTH        1
#define HANDLE_LENGTH        2

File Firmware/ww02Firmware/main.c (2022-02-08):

/*
 * main.c
 *
 *  Created on: Jan 2, 2019
 *      Author: KLockwood
 */

#include <stdint.h>
#include <string.h>
#include "nordic_common.h"
#include "nrf.h"
#include "nrf_error.h"
#include "app_error.h"
#include "ble.h"
#include "sdk_config.h"
#include "nrf_drv_clock.h"

//Project Includes
#include "project_settings.h"
#include <FreeRTOS/FreeRTOS_includes.h>
#include "mw_power_management.h"
#include "mw_logging.h"
#include "mw_cli_thread.h"

#include <mw_ble_peripheral_thread.h>
#include "mw_ble_central_thread.h"

#include "mw_sensor_thread.h"
#include "mw_adc_thread.h"
#include "mw_leds_thread.h"
#include "mw_temperature_thread.h"
#include "mw_rtc_thread.h"
#include "mw_data_manager_thread.h"
#include "mw_flash_thread.h"
#include "artic_thread.h"
#include "wwf_service.h"
#include "mw_watchdog.h"

#if BLE_PERIPHERAL_THREAD_ENABLED && BLE_CENTRAL_THREAD_ENABLED
#warning Multi-mode Central and Peripheral roles not currently supported
#endif

#define DEAD_BEEF                   0xDEADBEEF                              /**< Value used as error code on stack dump, can be used to identify stack location on stack unwind. */

/****************************************************************************************************/
/****************************************************************************************************/

/**@brief Callback function for asserts in the SoftDevice.
 *
 * @details This function will be called in case of an assert in the SoftDevice.
 *
 * @warning This handler is an example only and does not fit a final product. You need to analyze
 *          how your product is supposed to react in case of Assert.
 * @warning On assert from the SoftDevice, the system can only recover on reset.
 *
 * @param[in]   line_num   Line number of the failing ASSERT call.
 * @param[in]   file_name  File name of the failing ASSERT call.
 */
void assert_nrf_callback(uint16_t line_num, const uint8_t * p_file_name)
{
    app_error_handler(DEAD_BEEF, line_num, p_file_name);
}

/****************************************************************************************************/
/****************************************************************************************************/

/**@brief Function for initializing the clock.
 *
 * Using legacy driver, nrfx driver seems to cause issues
 */
static void clock_init(void)
{
	ret_code_t err_code = nrf_drv_clock_init(/*nrf_clock_handler*/);
	APP_ERROR_CHECK(err_code);
}



/****************************************************************************************************/
/****************************************************************************************************/

/**
 * @brief Function for initializing the board
 */
static void board_init(void)
{
  /* Initial Power Management */
  mw_power_management_init();
  mw_set_master_3V3_rail(ON);
  mw_set_1V8_rail(OFF);
  mw_set_artic_3V3_rail(OFF);
  mw_set_5V_rail(OFF);

  nrf_gpio_cfg_output(SPIM2_MISO_PIN);
  nrf_gpio_cfg_output(SPIM2_MOSI_PIN);
  nrf_gpio_cfg_output(SPIM2_SCK_PIN);
  nrf_gpio_cfg_output(SPIM2_SS_PIN);

  nrf_gpio_pin_clear(SPIM2_MISO_PIN);
  nrf_gpio_pin_clear(SPIM2_MOSI_PIN);
  nrf_gpio_pin_clear(SPIM2_SCK_PIN);
  nrf_gpio_pin_clear(SPIM2_SS_PIN);
}


/**
 * @brief - Initialize Watchdog
 */
static void wdt_init()
{
  mw_watchdog_init();
}


/****************************************************************************************************/
// This module is used to assure FPU events are handled so the system can return to proper
// idle sleep current as per Nordic recommendation:
// https://devzone.nordicsemi.com/question/70989/fpu-divide-by-0-and-high-current-consumption/
#define FPU_EXCEPTION_MASK 0x0000009F

//@FPU
void SETUP_FPU_HANDLER()
{
  NVIC_SetPriority(FPU_IRQn, APP_IRQ_PRIORITY_LOW);
  NVIC_EnableIRQ(FPU_IRQn);
}

void FPU_IRQHandler(void)
{
    uint32_t *fpscr = (uint32_t *)(FPU->FPCAR+0x40);
    (void)__get_FPSCR();

    *fpscr = *fpscr & ~(FPU_EXCEPTION_MASK);
}
/****************************************************************************************************/
/****************************************************************************************************/


/**@brief Function for application main entry.
 */
int main(void)
{
  /* Initialize clock module */
 	clock_init();


 	/* Setup FPU Handler */
 	SETUP_FPU_HANDLER();


  /* Initialize board */
	board_init();


  /* Initialize watchdog module */
  wdt_init();


#if TEMPERAURE_THREAD_ENABLED || SENSOR_THREAD_ENABLED || RTC_THREAD_ENABLED || ARTIC_THREAD_ENABLED
	nrfx_gpiote_init();
#endif

#if LOGGING_THREAD_ENABLED
	mw_logging_init();
#endif


#if CLI_THREAD_ENABLED
  mw_cli_thread_init();
#endif


#if RTC_THREAD_ENABLED
  mw_rtc_thread_init();
#endif


#if BLE_PERIPHERAL_THREAD_ENABLED
  mw_ble_peripheral_thread_init();
#elif !BLE_PERIPHERAL_THREAD_ENABLED && FLASH_THREAD_ENABLED
  mw_ble_peripheral_stack_init();
#endif

#if BLE_CENTRAL_THREAD_ENABLED
  mw_ble_central_thread_init();
#endif


#if ADC_THREAD_ENABLED
  mw_adc_thread_init();
#endif


#if SENSOR_THREAD_ENABLED
	mw_sensor_thread_init();
#endif


#if LED_THREAD_ENABLED
	mw_leds_thread_init();
#endif


#if TEMPERAURE_THREAD_ENABLED
	mw_temperature_thread_init();
#endif


#if ARTIC_THREAD_ENABLED
  artic_thread_init();
#endif



#if FLASH_THREAD_ENABLED
  mw_flash_thread_init();
#endif


#if DATA_MANAGER_THREAD_ENABLED
  mw_data_manager_thread_init();
#endif


	// Activate deep sleep mode
	SCB->SCR |= SCB_SCR_SLEEPDEEP_Msk;

	// Start FreeRTOS scheduler.
	vTaskStartScheduler();

	for (;;)
	{
		APP_ERROR_HANDLER(NRF_ERROR_FORBIDDEN);
	}
}

/****************************************************************************************************/
/****************************************************************************************************/

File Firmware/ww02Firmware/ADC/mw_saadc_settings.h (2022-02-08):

/*
 * mw_saadc_settings.h
 *
 *  Created on: Jan 28, 2019
 *      Author: klockwood
 */

#ifndef MW_SAADC_SETTINGS_H_
#define MW_SAADC_SETTINGS_H_

//#include "nrf_saadc.h"


/**********************************************************
 *
 * 				ADC SETTINGS
 *
 **********************************************************/
#define MW_SAADC_TIMER_INSTANCE                 1     // Use NRFX_TIMER1

#ifndef MW_SAADC_SAMPLE_INTERVAL
#define MW_SAADC_SAMPLE_INTERVAL                5000  // 5msec interval
#endif

#define MW_SAADC_MAXIMUM_CHANNELS		  					3		// Maximum number of channels for SAADC
#define MW_SAADC_SAMPLES_IN_BUFFER							MW_SAADC_MAXIMUM_CHANNELS //(MW_SAADC_MAXIMUM_CHANNELS * MW_SAADC_CONFIG_OVERSAMPLE)

#define MW_SAADC_ACQUIRE_MODE							      NRF_SAADC_BURST_DISABLED // NRF_SAADC_BURST_DISABLED NRF_SAADC_BURST_ENABLED

#define MW_SAADC_RESOLUTION											NRF_SAADC_RESOLUTION_12BIT
#define MW_SAADC_RESOLUTION_VALUE								(1U << (8 + ( 2 * MW_SAADC_RESOLUTION )))

#define MW_SAADC_REFERENCE											NRF_SAADC_REFERENCE_INTERNAL 	// NRF_SAADC_REFERENCE_INTERNAL NRF_SAADC_REFERENCE_VDD4
#define MW_SAADC_ACQ_TIME	 											NRF_SAADC_ACQTIME_40US; 			// NRF_SAADC_ACQTIME_3US NRF_SAADC_ACQTIME_10US NRF_SAADC_ACQTIME_15US NRF_SAADC_ACQTIME_20US NRF_SAADC_ACQTIME_40US
#define MW_SAADC_GAIN		 												NRF_SAADC_GAIN1_6 						// NRF_SAADC_GAIN1_4  NRF_SAADC_GAIN1_6

#if (MW_SAADC_GAIN == NRF_SAADC_GAIN1_6)
#define MW_SAADC_GAIN_VALUE											(0.166666666667f)
#elif (MW_SAADC_GAIN == NRF_SAADC_GAIN1_5)
#define MW_SAADC_GAIN_VALUE											(0.2f)
#elif (MW_SAADC_GAIN == NRF_SAADC_GAIN1_4)
#define MW_SAADC_GAIN_VALUE											(0.25f)
#elif (MW_SAADC_GAIN == NRF_SAADC_GAIN1_3)
#define MW_SAADC_GAIN_VALUE											(0.333333333333f)
#elif (MW_SAADC_GAIN == NRF_SAADC_GAIN1_2)
#define MW_SAADC_GAIN_VALUE											(0.5f)
#elif (MW_SAADC_GAIN == NRF_SAADC_GAIN1)
#define MW_SAADC_GAIN_VALUE											(1f)
#elif (MW_SAADC_GAIN == NRF_SAADC_GAIN2)
#define MW_SAADC_GAIN_VALUE											(2f)
#elif (MW_SAADC_GAIN == NRF_SAADC_GAIN4)
#define MW_SAADC_GAIN_VALUE											(4f)
#endif

#if (MW_SAADC_REFERENCE == NRF_SAADC_REFERENCE_INTERNAL)
#define MW_SAADC_REF_VOLTAGE										(0.6f) 												// Voltage value of MW_SAADC_REFERENCE setting
#else
#define MW_SAADC_REF_VOLTAGE										(0.825f) 											// Voltage value of MW_SAADC_REFERENCE setting
#warning Warning: verify this value equals VDD/4
#endif

// <o> MW_SAADC_CONFIG_RESOLUTION  - Resolution
// <0=> 8 bit
// <1=> 10 bit
// <2=> 12 bit
// <3=> 14 bit
#define MW_SAADC_CONFIG_RESOLUTION  2

// <o> MW_SAADC_CONFIG_OVERSAMPLE  - Sample period
// <0=> Disabled
// <1=> 2x
// <2=> 4x
// <3=> 8x
// <4=> 16x
// <5=> 32x
// <6=> 64x
// <7=> 128x
// <8=> 256x
#define MW_SAADC_CONFIG_OVERSAMPLE  0

// <q> MW_SAADC_CONFIG_LP_MODE  - Enabling low power mode
#define MW_SAADC_CONFIG_LP_MODE     0


// <o> MW_SAADC_CONFIG_IRQ_PRIORITY  - Interrupt priority
// <0=> 0 (highest)
// <1=> 1
// <2=> 2
// <3=> 3
// <4=> 4
// <5=> 5
// <6=> 6
// <7=> 7
#define MW_SAADC_CONFIG_IRQ_PRIORITY 3


/**
 * @brief Macro for setting ADC Pin Settings
 *        in single ended mode.
 *
 * @param PIN_P Analog input.
 */
#define MW_SAADC_DEFAULT_CHANNEL_CONFIG_SE (ADC_PIN) 	\
{																											\
    .resistor_p = NRF_SAADC_RESISTOR_DISABLED,      	\
    .resistor_n = NRF_SAADC_RESISTOR_DISABLED,      	\
    .gain       = NRF_SAADC_GAIN1_6,                	\
    .reference  = NRF_SAADC_REFERENCE_VDD4,     			\
    .acq_time   = NRF_SAADC_ACQTIME_10US,           	\
    .mode       = NRF_SAADC_MODE_SINGLE_ENDED,      	\
    .burst      = NRF_SAADC_BURST_DISABLED,         	\
    .pin_p      = (nrf_saadc_input_t)(ADC_PIN),     	\
    .pin_n      = NRF_SAADC_INPUT_DISABLED          	\
}




/**
 * @brief Macro for setting ADC pin in Differential Mode
 *
 * @param PIN_P Positive analog input.
 * @param PIN_N Negative analog input.
 */
#define MW_SAADC_DEFAULT_CHANNEL_CONFIG_DIFFERENTIAL (PIN_P, PIN_N)   \
{                                                                    \
    .resistor_p = NRF_SAADC_RESISTOR_DISABLED,                       \
    .resistor_n = NRF_SAADC_RESISTOR_DISABLED,                       \
    .gain       = NRF_SAADC_GAIN1_6,                                 \
    .reference  = NRF_SAADC_REFERENCE_INTERNAL,                      \
    .acq_time   = NRF_SAADC_ACQTIME_10US,                            \
    .mode       = NRF_SAADC_MODE_DIFFERENTIAL,                       \
    .pin_p      = (nrf_saadc_input_t)(PIN_P),                        \
    .pin_n      = (nrf_saadc_input_t)(PIN_N)                         \
}

#endif /* MW_SAADC_SETTINGS_H_ */

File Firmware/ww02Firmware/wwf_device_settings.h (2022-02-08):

/*
 * wwf_device_settings.h
 *
 *  Created on: Feb 18, 2020
 *      Author: klockwood
 */

#ifndef WWF_DEVICE_SETTINGS_H_
#define WWF_DEVICE_SETTINGS_H_

#include "project_settings.h"
#include "mw_rtc_thread.h"

/* Number of Argos Transmission Repeats per Transmission Cycle */
#define DEFAULT_TRANSMISSION_REPITIIONS       60


/* Interval time (milliseconds) between repeated Argos Transmissions */
#define DEFAULT_TRANSMISSION_INTERVAL        (30 * 1000)//(90 * 1000)  /* 90 seconds */


/* Time Duration of a Data Gather Time Slot */
#define PROFILE_DATA_GATHER_INTERVAL         (5)
#define PROFILE_DATA_GATHER_INTERVAL_UNITS   RTC_MINUTES
/*  RTC_SECONDS
    RTC_MINUTES
    RTC_HOURS
    RTC_DAYS   */



/* Number of Data Time Slots Gathers before Transmitting */
#define PROFILE_DATA_GATHER_INDEX_MAX        2 //(14)   /*Sensor Capture Windows*/


/* Default Bear ID value */
#define DEFAULT_BEAR_ID_AND_PROFILE          0xACE // 0xACE  0xDAD


/******************************************
 * ARGOS ID associated with MW account
 * 173498  ->  0x2B978AD
 * 173499  ->  0x2B978BE
 * 173500  ->  0x2B978C7
*******************************************/
#define DEFAULT_ARGOS_28BIT_ID_FIELD         0x2B978AD

/*
 * Project Timer Intervals *
 */
#ifdef BATTERY_MEASUREMENT_INTERVAL
#undef BATTERY_MEASUREMENT_INTERVAL
#define BATTERY_MEASUREMENT_INTERVAL         60000         /**< Battery level measurement interval (ms). */
#endif


#ifdef TEMPERATURE_TIME_INTERVAL
#undef TEMPERATURE_TIME_INTERVAL
#define TEMPERATURE_TIME_INTERVAL            300000
#endif

#endif /* WWF_DEVICE_SETTINGS_H_ */

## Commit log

2022-02-08 Intital commit to upload files from bit-bucket
2022-04-27 Refactored to house firmware, electrical, mechanical
    [90358A009_Ultra-Low-Profile Socket Head Screw.SLDPRT, 90591A109_Zinc-Plated Steel Hex Nut.SLDPRT, 90592A090_Steel Hex Nut.SLDPRT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]
2022-04-28 Added Urethane mold files
    [90592A090_STEEL HEX NUT.SLDPRT, ASSEM Potted Case Mold.SLDASM, Mold Clamp 1.SLDPRT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]
2022-05-17 Added logos and fix firmware folder
    [Bill of Materials-WW02_Mini(Production).xlsx, PickPlaceforWW02Mini.csv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]
